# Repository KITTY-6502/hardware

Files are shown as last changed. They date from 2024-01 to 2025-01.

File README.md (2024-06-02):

# KITTY Computer

the KITTY is a 65c02 homebrew kit microcomputer designed around text mode graphics and cartridge media. It is fully open source, and uses exclusively in-production parts. 

Quick Specs:

* **Bus Speed:** 3Mhz
* **CPU:*** w65c02s @~2.2Mhz (average)
* **RAM:** 28Kb SRAM
* **Video:** Custom, 256x256pixels, a text mode display using a preset font, 32x32 8x8 pixel characters, 16 color palette
* **Sound:** Custom, 8x1 Wavetable Audio, 3 melodic + 1 percussive channels, all with 4bit+4bit stereo volume control.
* **Input:** 40-Key Mechanical Keyboard
* **Media/Expansion:** 2 Cartridge Slots, each with up to 128x32Kb banks.
* **Interrupts:** /IRQ triggered when the video circuit has drawn the last visible pixels on the frame.
* **Output:** RGB PAL (50hz), via a SCART connector.

**[Computer Manual](https://smaldragon.github.io/KITTY)**
**[Schematic](Docs/schematics/v2a.pdf)**

Picture of Prototype Board
Test Program

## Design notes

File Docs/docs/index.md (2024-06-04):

# What is a KITTY? (an introduction)

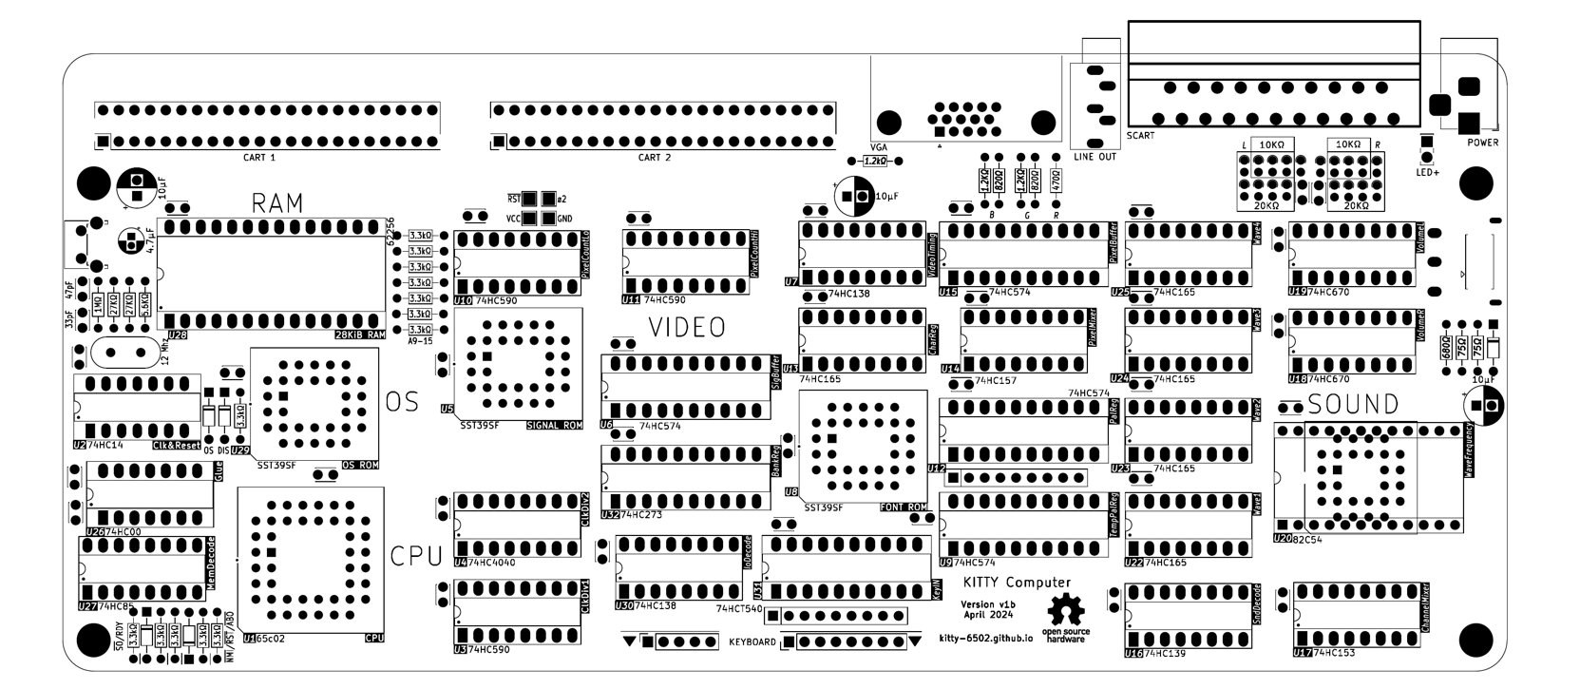
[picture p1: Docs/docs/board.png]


The **KITTY** (Kewl Interactive Text Terminal sYstem) is a new 8bit 65c02-based fantasy homebrew computer developed by smal (that's me!), it envisions a microcomputer which never existed, with colorful text based graphics, an unique sound system and, oddly, cartridges as its main form of media and expansion.

Looking at the back of the system, we see an austere sight: An audio/video SCART port and two cartridge ports, and not a single peripheral port in sight! In fact, the basic cartridge that came bundled with every sold system had to include audio jacks on the cart itself in order to allow one to save their programs. Rather than a failure, this was the driving design philosphy behind the cost-saving design of the KITTY, to allow programs to come bundled with any extra features they might need, while leaving the base design unburdened, after all, what use would an extra port or feature be without an accompaning program to use it?

Sadly we do not have access to this particular alternate reality (perhaps because it is imaginary), so we can not judge the success of this particular design approach. However, I have designed and built a version of this system here in our own world for anyone to play with, and this is what this manual is all about.

I wish you a fun and (hopefully) educational time exploring this little system



> The original v0a board prototype

## Details

The current iteration of the KITTY board (v1a) uses only in-production parts and is open hardware that anyone can tweak and build upon, on the v1a board custom features like video and audio are all implemented through the means of discrete 74-series logic. All ICs are in either Dual-In-Line packages or PLCC packages using through hole sockets, so that no surface mount soldering is required for assembly and all ICs can be easily placed or removed.

Finally, all components, their values, and their general function within the circuit are written on the silkscreen itself, as I wanted a board that was easy to assemble and understand.

## SPECS

* **CPU** 65c02 @ ~2.2mhz (3mhz bus)
* **RAM** 28Kb Static Ram
* **MEDIA** 2 cartridge slots for programs or expansion, each with up to 128 banks of 32kb for a theoretical max of 4Mb per cartridge
* **VIDEO** Custom, 8x8 pixel characters on a 32x32 grid, selectable background/foreground colors from a pallette of 16 
* **AUDIO** Custom, 4 channels of 8x1 wavetable audio (3 melodic, 1 percussive), with 4bit+4bit stereo volume control
* **INPUT** Custom 40-key mechanical keyboard 
* **OUTPUT** SCART, using RGB progressive PAL @50.1hz
* **POWER** 5v DC via a center positive barrel jack

```
    .--------------------.                          .----------------------.
    | 64KiB Memory Space |                          |          I/O         |
    |--------------------|                          |--------------+-------|
    |                    | $0000                    | KEY 1        | $7000 |
    |                    | $0800                    | KEY 2        | $7010 |
    |                    | $1000                    | KEY 3        | $7020 |
    |                    | $1800                    | KEY 4        | $7030 |
    |                    | $2000                    | KEY 5        | $7040 |
    |      WORK RAM      | $2800                    | BANK Register| $70D0 |
    |       28KiB        | $3000                    | CH Freq 1    | $70E0 |
    |                    | $3800                    | CH Freq 2    | $70E1 |
    |                    | $4000                    | CH Freq 3    | $70E2 |
    |                    | $4800                    | CH Control   | $70E3 |
    |                    | $5000                    | CH Volume 1  | $70F0 |
    |                    | $5800                    | CH Volume 2  | $70F1 |
    |                    | $6000                    | CH Volume 3  | $70F2 |
    |   (video memory)   | $6800                    | CH Volume 4  | $70F3 |
    |--------------------| $7000                    | CH Waveform 1| $70F4 |
    |        I/O         | $7800                    | CH Waveform 2| $70F5 |
    |--------------------| $8000                    | CH Waveform 3| $70F6 |
    |                    | $8800                    | CH Waveform 4| $70F7 |
    |                    | $9000                    +--------------+-------+
    |                    | $9800
    |                    | $A000
    |     CART SPACE     | $A800
    |       32KiB        | $B000
    |    (256 Banks)     | $B800
    |                    | $C000
    |                    | $C800
    |                    | $D000
    |                    | $D800
    |                    | $E000
    |                    | $E800
    |                    | $F000
    |                    | $F800
    +--------------------+

```

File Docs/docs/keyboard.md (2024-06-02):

# Keyboard

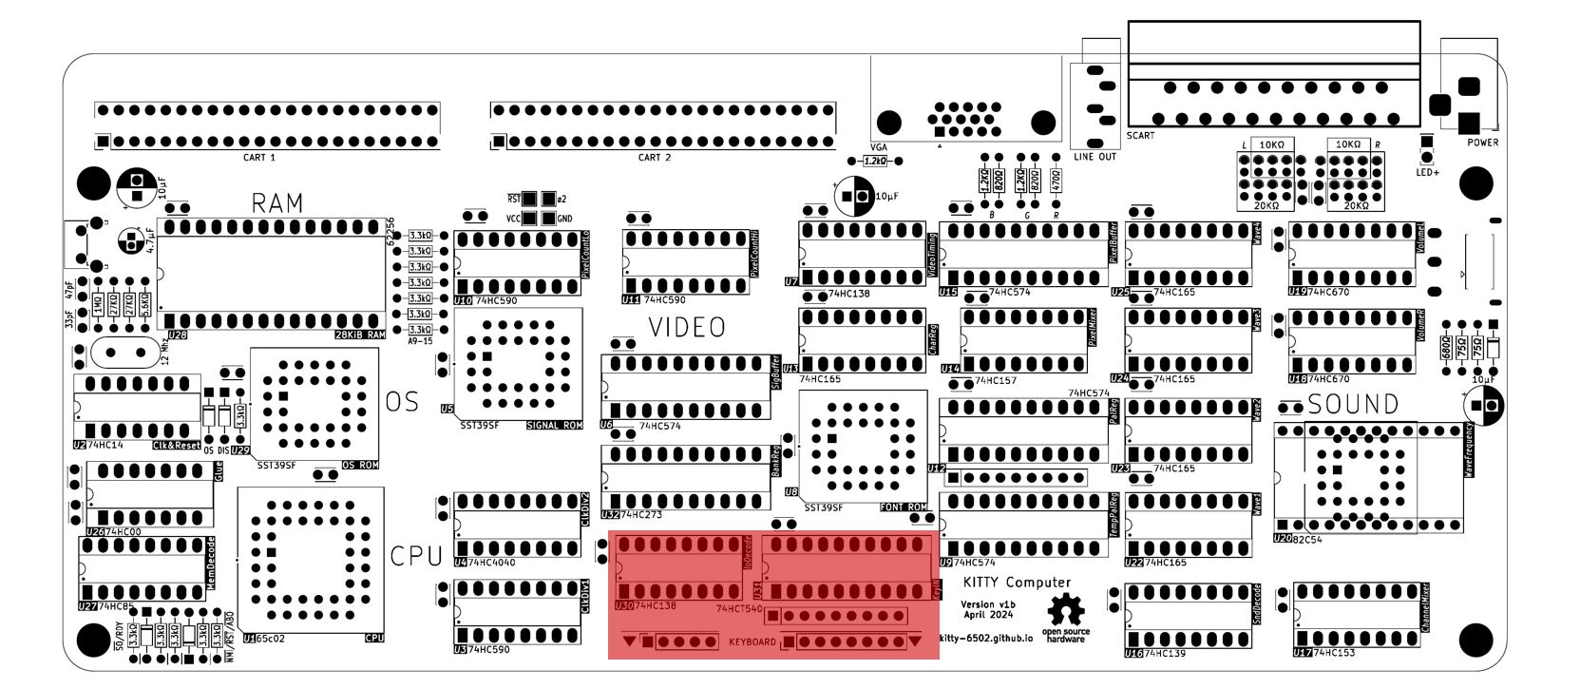
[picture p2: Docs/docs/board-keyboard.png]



The KITTY uses a custom 40-key mechanical keyboard for input, which is connected to the main board via two cables.

The keyboard can be read directly by the cpu through means of 5 Keyboard Row Registers, where each bit in the byte represents the current state of a particular key (**0**=unpressed **1**=pressed).

| Address | Mode |  Description | Format (bit 7-0)|
|---|---|---|---|
| `$7000` |  R | Keyboard Row 1 | `Ctrl` `X` `C` `Space` `↑` `←` `↓` `→` |
| `$7010` |  R | Keyboard Row 2 | `Menu` `Z` `F` `B` `N` `|` `.` `Enter` |
| `$7020` |  R | Keyboard Row 3 | `Shift` `A` `D` `V` `H` `M` `L` `Backspace`|
| `$7030` |  R | Keyboard Row 4 | `Alt` `Q` `S` `G` `Y` `J` `K` `P`|
| `$7040` |  R | Keyboard Row 5 | `Esc` `W` `E` `R` `T` `U` `I` `O`|

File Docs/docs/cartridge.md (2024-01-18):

# Cartridges and Memory

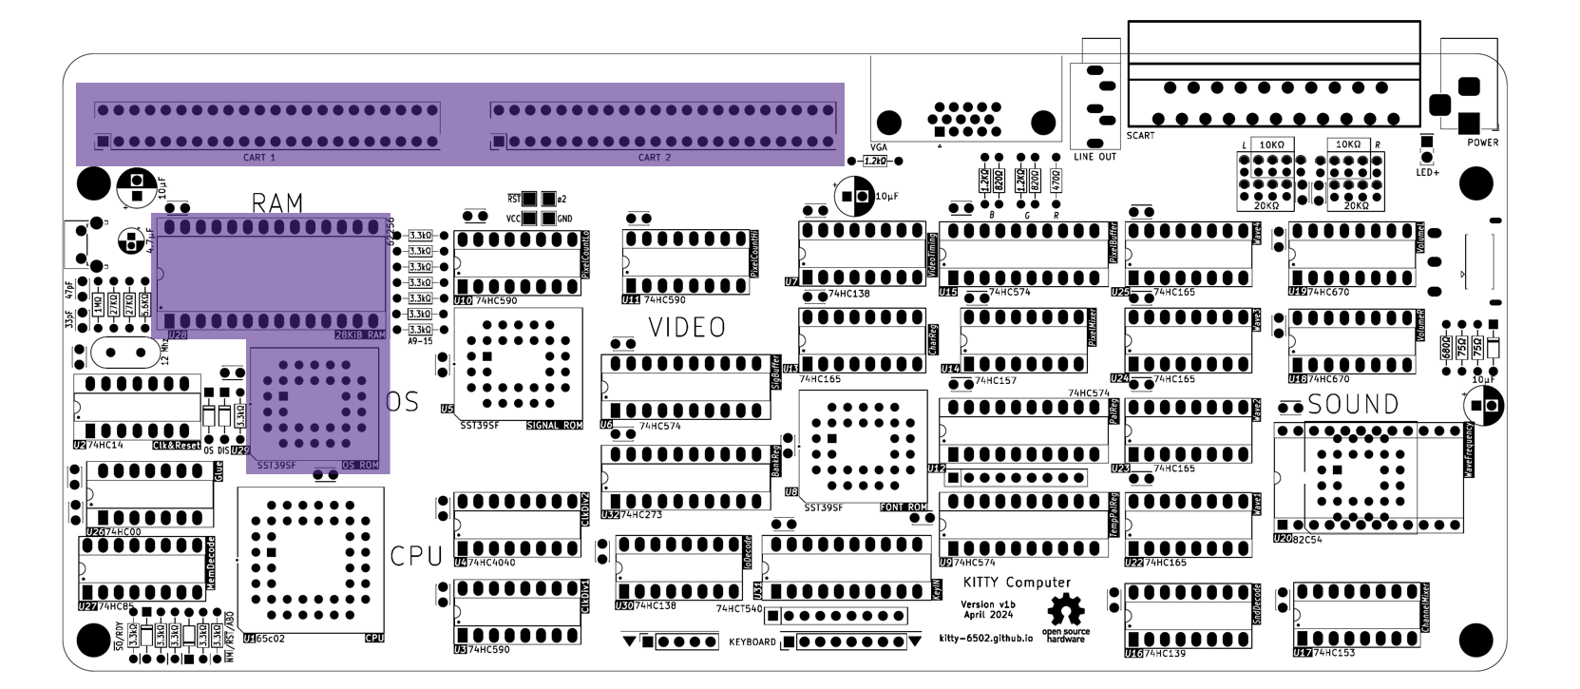
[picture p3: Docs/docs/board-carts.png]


| Address | Mode |  Description | Format |
|---|---|---|---|
| `$0000-$6FFF`| R/W | System Ram | 28Kb of static ram |
| `$70D0` |  W | BANK Register  | `%cccc_bbbb` **c**artridge `0-1` and **b**ank `0-127` |
| `$8000-$FFFF` | R/W | Cartridge Space | 32Kb banked window

Cartridges are the main form of media and expansion used by the KITTY, with the system being able to hold 2 cartridges at a time (dubbed Slot 1 and Slot 2), each of which have an individual 4Mb address space, that can be filled with programs, extra ram or peripheral devices.

They are accessed through the upper half of the KITTY memory map (`$8000-$FFFF`), which acts as 32Kb window into the contents of one of the 2 carts. This window can then be controlled by writing to the BANK register located at `$70D0`. The upper bit will determine the cartridge, while the 7 remaining bits will select one of up to 128 banks within it.

Finally, on hardware reset/power-on the BANK register will always be cleared to $00. As such, CPU will always begin code execution from the Bank 0 of Slot 1.

## OS ROM

The "OS ROM" or "TEST ROM" is a rom present on the main KITTY PCB, which is virtuaslly mapped to cartridge Slot 1. As of time of writing (2024-01-05), the contents of this chip have not been defined.

## Cartridge Pinout

The 2 cartridge slots use standard right-angle edge connectors, with 44-pins, and a spacing of 2.54mm (0.1"):



* `D0-D7`  - 8bit data bus
* `A0-A15` - 16bit address bus
* `B0-B7`  - 8bit BANK register
* `M3`     - 3Mhz Bus Clock
* `R/#W`   - Read/Write Signal, standard 65xx polarity
* `#R/W`   - Read/Write Signal, inverted polarity
* `#RESET` - System Reset
* `#NMI`   - Non-Maskable Interrupt
* `#CART`  - Cartridge Space Access `A15 NAND M3`
* `#SLOT ENABLE`- If the current slot is enabled (according to bit 7 of BANK)
* `ROM DISABLE` - Disable OS ROM (slot 1 only)
* `x` - Unconnected

`ROM DISABLE` is a signal that, when pulled high by a cartridge in Slot 1, disables the OS ROM. A cart can choose to leave this signal permanently high, to completely replace the OS ROM, or it can instead choose to implement more complex address decoding logic, allowing both to coexist within the same slot.

# Flash ROM Cart

The flash cart uses a standard re-writable 39sf flash NOR chip, which are avaliable in sizes of 128KiB, 256KiB and 512KiB.

# Serial Cart

The serial cart allows communication between the KITTY and a modern computer via serial over USB, the KITTY is connected to a `16c550` UART, while the desktop is connected to a `MCP2221A` UART. The cart shares slot 1 with the **OS ROM**, being active/replacing it when **BANK** is `$40` or higher (bit 6 high)

# RAM Cart

The RAM cart provides either 128KiB or 512KiB of SRAM memory.

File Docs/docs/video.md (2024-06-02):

# Video System

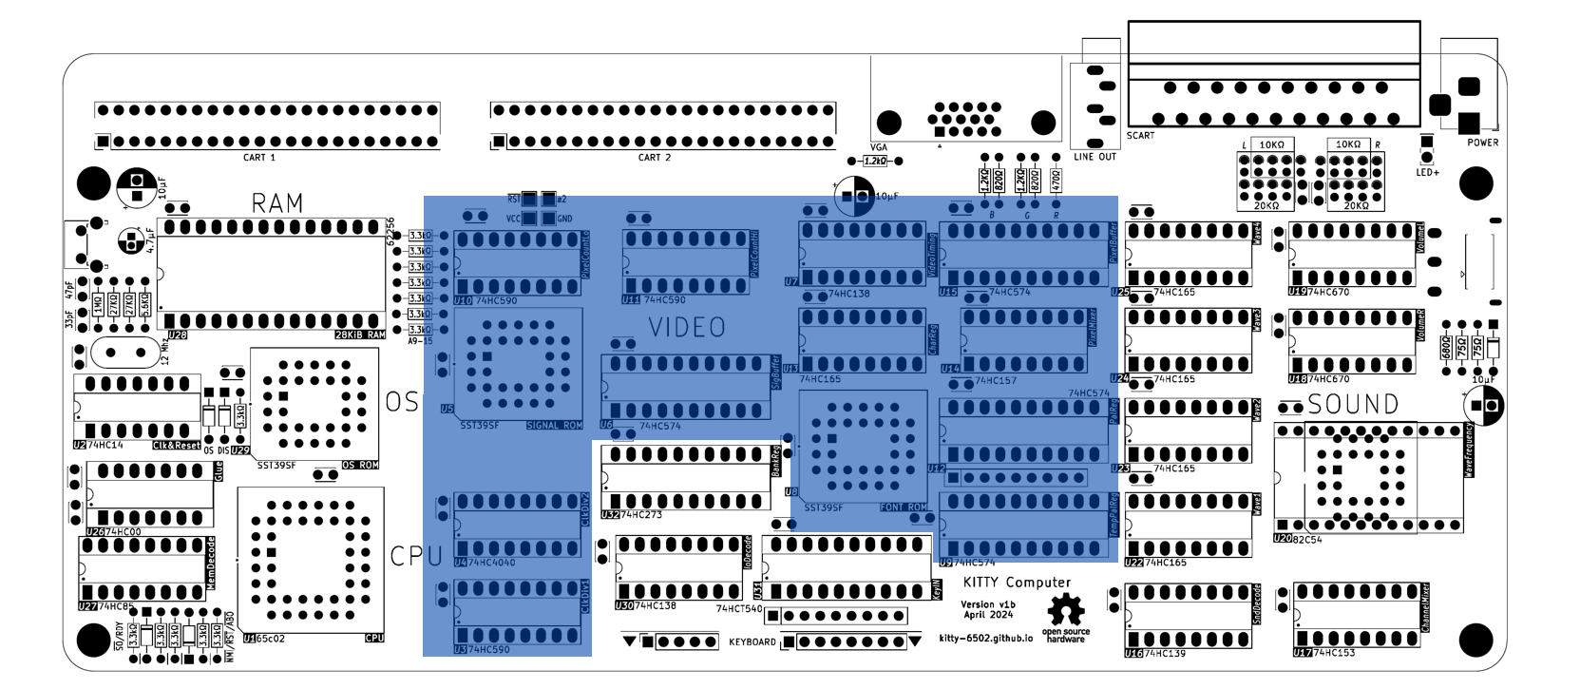
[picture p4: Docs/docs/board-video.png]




The KITTY's video output is a text based display containing 32 by 32 tiles of 8 by 8 pixels. Each tile can be set to one of 256 different characters from a fixed font, with foreground and background colors chosen from a palette of 16.

The data for the display is located directly in system ram:

| Address |  Description | Format |
|---|---|---|
| `$6800-$6BFF` | Display Characters | `0-255` extended ascii character |
| `$6C00-$6FFF` | Display Color | `%ffff_bbbb` **f**oreground and **b**ackground |

## Palette

An approximation of the KITTY's color palette:



## Font

The font is a variation of ascii:

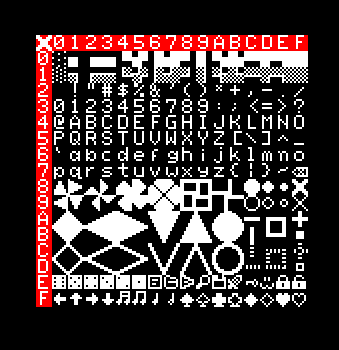
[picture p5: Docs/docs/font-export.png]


# Details

The color palette is generated from the following resistor DAC:



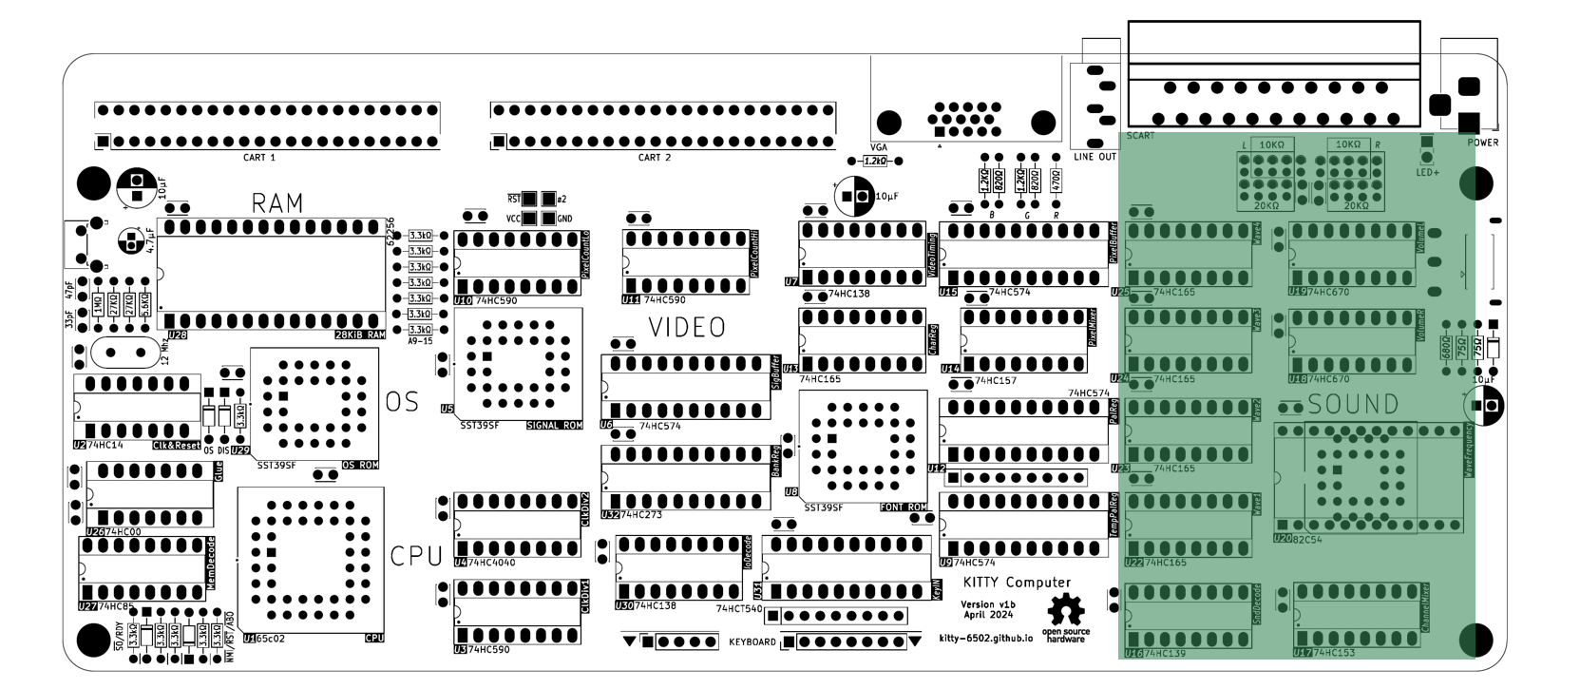
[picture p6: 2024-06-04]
Docs/docs/board-audio.png

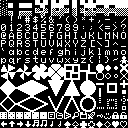
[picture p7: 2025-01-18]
Code/font.png

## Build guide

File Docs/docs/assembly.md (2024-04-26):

# System Assembling

## Bill of Materials

### Integrated Circuits

Name        | Qty | Package             | Description
------------|-----|---------------------|-------------
74HC00      |  1  | dip-14              | quad NAND
74HC14      |  1  | dip-14              | hex NOT (Schmitt-Trigger)
74HC85      |  1  | dip-16              | 4-bit Comparator
74HC138     |  2  | dip-16              | 3to8 Decoder
74HC139     |  1  | dip-16              | dual 2to4 Decoder
74HC153     |  1  | dip-16              | dual 4to1 Selector
74HC157     |  1  | dip-16              | quad 2to1 Selector
74HC165     |  5  | dip-16              | parallel-in Shift Register
74HC273     |  1  | dip-20              | 8-bit Register w/Reset
74HC574     |  4  | dip-20              | 8-bit Register w/3-State
74HC590     |  3  | dip-16              | 8-bit Sync Counter
74HC670     |  2  | dip-16              | 4x4-bit Register
74HC4040    |  1  | dip-16              | 12-bit Ripple Counter
74HCT540    |  1  | dip-20              | 8-bit Buffer (Inverting)
82c54       |  1  | dip-24-wide/plcc-28 | Tripple Timer
62256       |  1  | dip-28-wide         | 32KiB Sram
39SF040     |  3  | plcc-32             | 512KiB Nor Flash
65c02       |  1  | plcc-44             | 8-bit CPU

### Sockets

Name        | Qty |
------------|-----|
dip-14      |  2  |
dip-16      | 17  |
dip-20      |  6  |
dip-24-wide*|  1  |
dip-28-wide |  1  |
plcc-28*    |  1  |
plcc-32     |  3  |
plcc-44     |  1  |

> *1 Use either dip-24w or plcc depending on chosen 82c54 package

### Passives

Type              | Value               | Qty |
------------------|---------------------|-----|
12Mhz Quartz      | HC49                |  1  |
Diode             | 1n4148              |  5  |
Led               | Rectangular 2mmx5mm |  1  |
Led Holder        | 15mm Holder         |  1  |
Ceramic Capacitor | 33pF                |  1  |
Ceramic Capacitor | 47pF                |  1  |
Ceramic Capacitor | 100nF               | 34  |
Polar   Capacitor | 4.7µF               |  1  |
Polar   Capacitor | 10µF                |  3  |
Resistor          | 75Ω                 |  2  |
Resistor          | 470Ω                |  1  |
Resistor          | 680Ω                |  1  |
Resistor          | 820Ω                |  2  |
Resistor          | 1.2KΩ               |  2  |
Resistor          | 3.3KΩ               | 12  |
Resistor          | 5.6KΩ               |  1  |
Resistor          | 10KΩ                |  6  |
Resistor          | 20KΩ                | 10  |
Resistor          | 27KΩ                |  2  |
Resistor          | 1MΩ                 |  1  |

#### Keyboard

Type              | Value               | Qty |
------------------|---------------------|-----|
Diode             | 1n4148              | 45  |

### Switches and Connectors

Type                                        | Qty | Function
--------------------------------------------|-----|-----------
5x2.1 DC Power Jack                         |  1  | Power In
SCART Female (no ears)                      |  1  | Audio/Video Out
PJ-325                                      |  1  | Audio Out
VGA Female Connector                        |  1  | Video Out
Right Angle 2.54mm 44Pin Edge Connector     |  2  | Cartridge Slot
Right Angle Tactile Switch                  |  1  | Reset Button
SS-12D11-G5 Slide Switch                    |  1  | Power Switch
8-pin 2.54mm JST Vertical                   |  1  | Keyboard Connector
5-pin 2.54mm JST Vertical                   |  1  | Keyboard Connector

#### Keyboard
Type                                        | Qty | Function
--------------------------------------------|-----|-----------
8-pin 2.54mm JST Horizontal                 |  1  | Keyboard Connector
5-pin 2.54mm JST Horizontal                 |  1  | Keyboard Connector
2.00U Stabilizer                            |  1  | Return Stabalizer
6.25U Stabilizer                            |  1  | Spacebar Stabalizer
MX Switch/Kailh Low-Profile                 | 40  | Keyboard Switches
1U KeyCap                                   | 32  | Letters, Arrows, Escape
1.25U KeyCap                                |  3  | BackSpace, Alt, Ctrl
1.5U KeyCap                                 |  1  | BackSlash
1.75U KeyCap                                |  2  | Shift, Math
2U KeyCap                                   |  1  | Enter
6.25U KeyCap                                |  1  | SpaceBar

Due to the uncommon layout of the keyboard, it is preferable to pick a set of keycaps using a profile of uniform height, such as:

* DSA
* XDA
* G20
* MOA
* KAT

## Assembly

This guide approachs assembling the KITTY through a series of steps where one subsystem is built, tested and debugged, before moving on to the next step. Hoping this way to both avoid mistakes, and give you a better understanding of how the system works.

### Step 1 - Power Input

Install Power Jack, Power Switch, Big Decap, Power LED & its resistor.

### Step 2 - Clock and Reset

Install '14 and the passives for the clock and reset

Pierce Oscillator circuit 

### Step 3 - Clock Dividers

Install '590 and '4040

### Step 4 - First "Video" Output

Install Sig ROM, '574, SCART and VGA Ports, Mode and Sync components

The signal ROM is controlled by the clock dividers built in the previous step, and is in charge of:

* generating the video sync signals
* determining the visible portion of the screen
* generating a CPU interrupt request when the very last character on a frame is rendered
* resetting the clock counters at the end of the frame.

Finally a '574 latch is used to buffer the output of the Sig ROM before sending it to the rest of the system (to avoid signal transition glitches)

Connecting a video cable to an appropriate known-working display, there will be no image yet, but the signal should now be recognized by the display as Progressive PAL 50fps (what your display calls may vary). If the display shows a "no signal" message then most likely a mistake was made somewhere in this building step.

### Step 5 - Random Colors

Coordination '138, BOXY palette buffers, BOXY color mixer, BOXY out buffer, Color DAC

### Step 6 - RAM, memory mapping, and Stable Colors

SRAM, '85, '00, '590, '590

###Step 7 - Random Characters

'165, FONT ROM

### Step 8 - Installing the CPU

'w65c02

### Step 9 - Adding the test rom

ROM, '138, '273

### Step 10 - The Keyboard

'541 + keyboard + headers

### Step 11 - Sound System

82c54, '670, '670, '153, Sound DAC, Sound Filters

### Step 12 - The Case

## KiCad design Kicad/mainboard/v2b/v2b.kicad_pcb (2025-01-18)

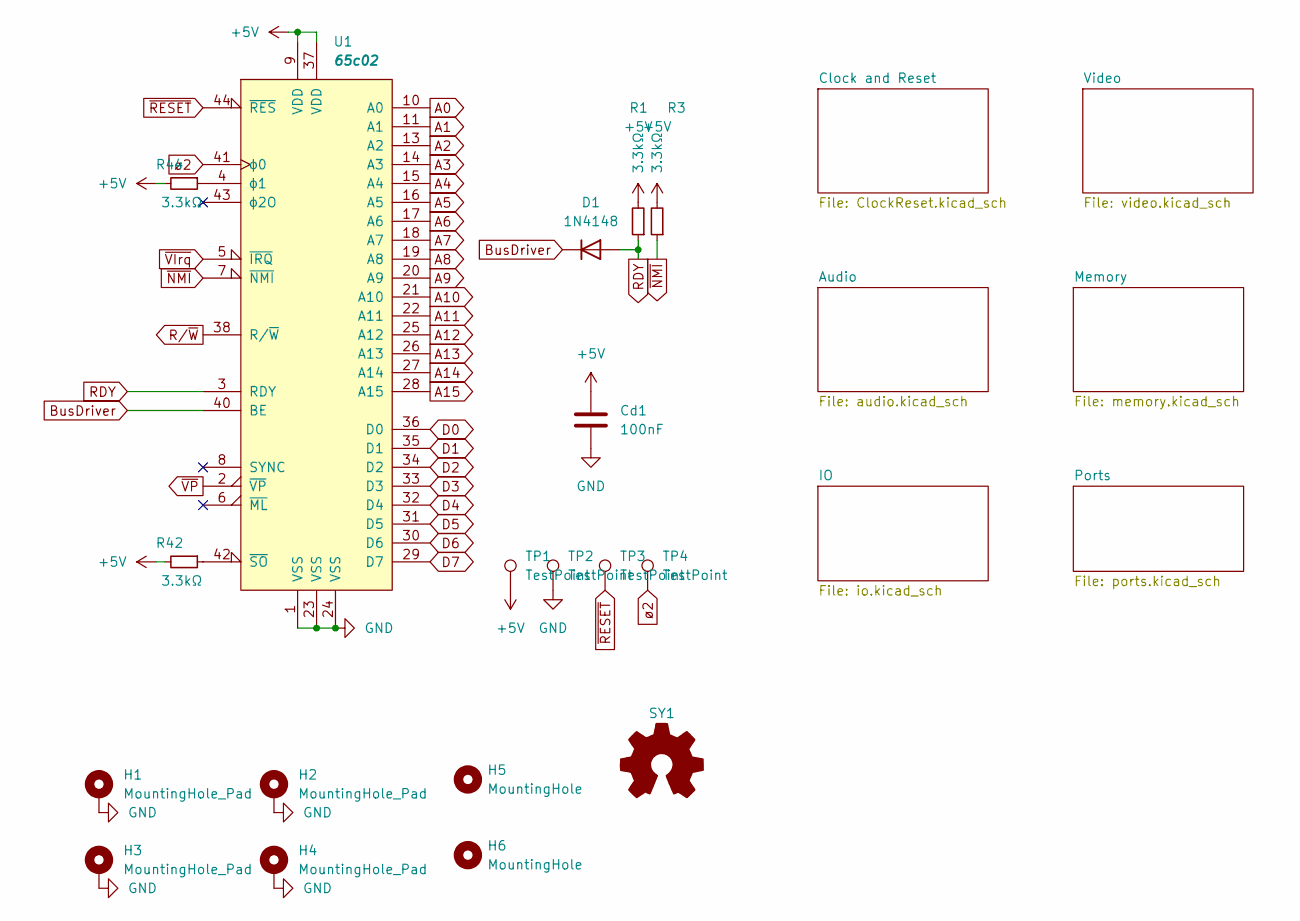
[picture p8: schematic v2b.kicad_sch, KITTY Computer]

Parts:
Cd1: 100nF; C_Disc_D3.0mm_W1.6mm_P2.50mm
D1: 1N4148; D_DO-34_SOD68_P7.62mm_Horizontal
H1, H2, H3, H4: MountingHole_Pad; MountingHole_3.2mm_M3_ISO14580_Pad
H5, H6: MountingHole; MountingHole_2.2mm_M2
R1, R3, R42, R44: 3.3kΩ; R_Horizontal
SY1: Logo_Open_Hardware_Small; OSHW-Logo_7.5x8mm_SilkScreen
TP1, TP2, TP3, TP4: TestPoint; TestPoint_Pad_2.0x2.0mm
U1: 65c02; PLCC-44_THT-Socket_TWEAK

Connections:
+5V: Cd1.1, R1.2, R3.2, R42.2, R44.2, TP1.1, U1.9 (VDD), U1.37 (VDD); also elsewhere on the board
A0: U1.10 (A0); also elsewhere on the board
A1: U1.11 (A1); also elsewhere on the board
A2: U1.13 (A2); also elsewhere on the board
A3: U1.14 (A3); also elsewhere on the board
A4: U1.15 (A4); also elsewhere on the board
A5: U1.16 (A5); also elsewhere on the board
A6: U1.17 (A6); also elsewhere on the board
A7: U1.18 (A7); also elsewhere on the board
A8: U1.19 (A8); also elsewhere on the board
A9: U1.20 (A9); also elsewhere on the board
A10: U1.21 (A10); also elsewhere on the board
A11: U1.22 (A11); also elsewhere on the board
A12: U1.25 (A12); also elsewhere on the board
A13: U1.26 (A13); also elsewhere on the board
A14: U1.27 (A14); also elsewhere on the board
A15: U1.28 (A15); also elsewhere on the board
BusDriver: D1.1 (K), U1.40 (BE); also elsewhere on the board
CLK2: TP4.1, U1.41 (ϕ0); also elsewhere on the board
D0: U1.36 (D0); also elsewhere on the board
D1: U1.35 (D1); also elsewhere on the board
D2: U1.34 (D2); also elsewhere on the board
D3: U1.33 (D3); also elsewhere on the board
D4: U1.32 (D4); also elsewhere on the board
D5: U1.31 (D5); also elsewhere on the board
D6: U1.30 (D6); also elsewhere on the board
D7: U1.29 (D7); also elsewhere on the board
GND: Cd1.2, H1.1, H2.1, H3.1, H4.1, TP2.1, U1.1 (VSS), U1.23 (VSS), U1.24 (VSS); also elsewhere on the board
unnamed: R42.1, U1.42 (~SO)
unnamed: R44.1, U1.4 (ϕ1)
RDY: D1.2 (A), R1.1, U1.3 (RDY)
R/~W: U1.38 (R/~W); also elsewhere on the board
~NMI: R3.1, U1.7 (~NMI); also elsewhere on the board
~RESET: TP3.1, U1.44 (~RES); also elsewhere on the board
~VIrq: U1.5 (~IRQ); also elsewhere on the board
~VP: U1.2 (~VP); also elsewhere on the board

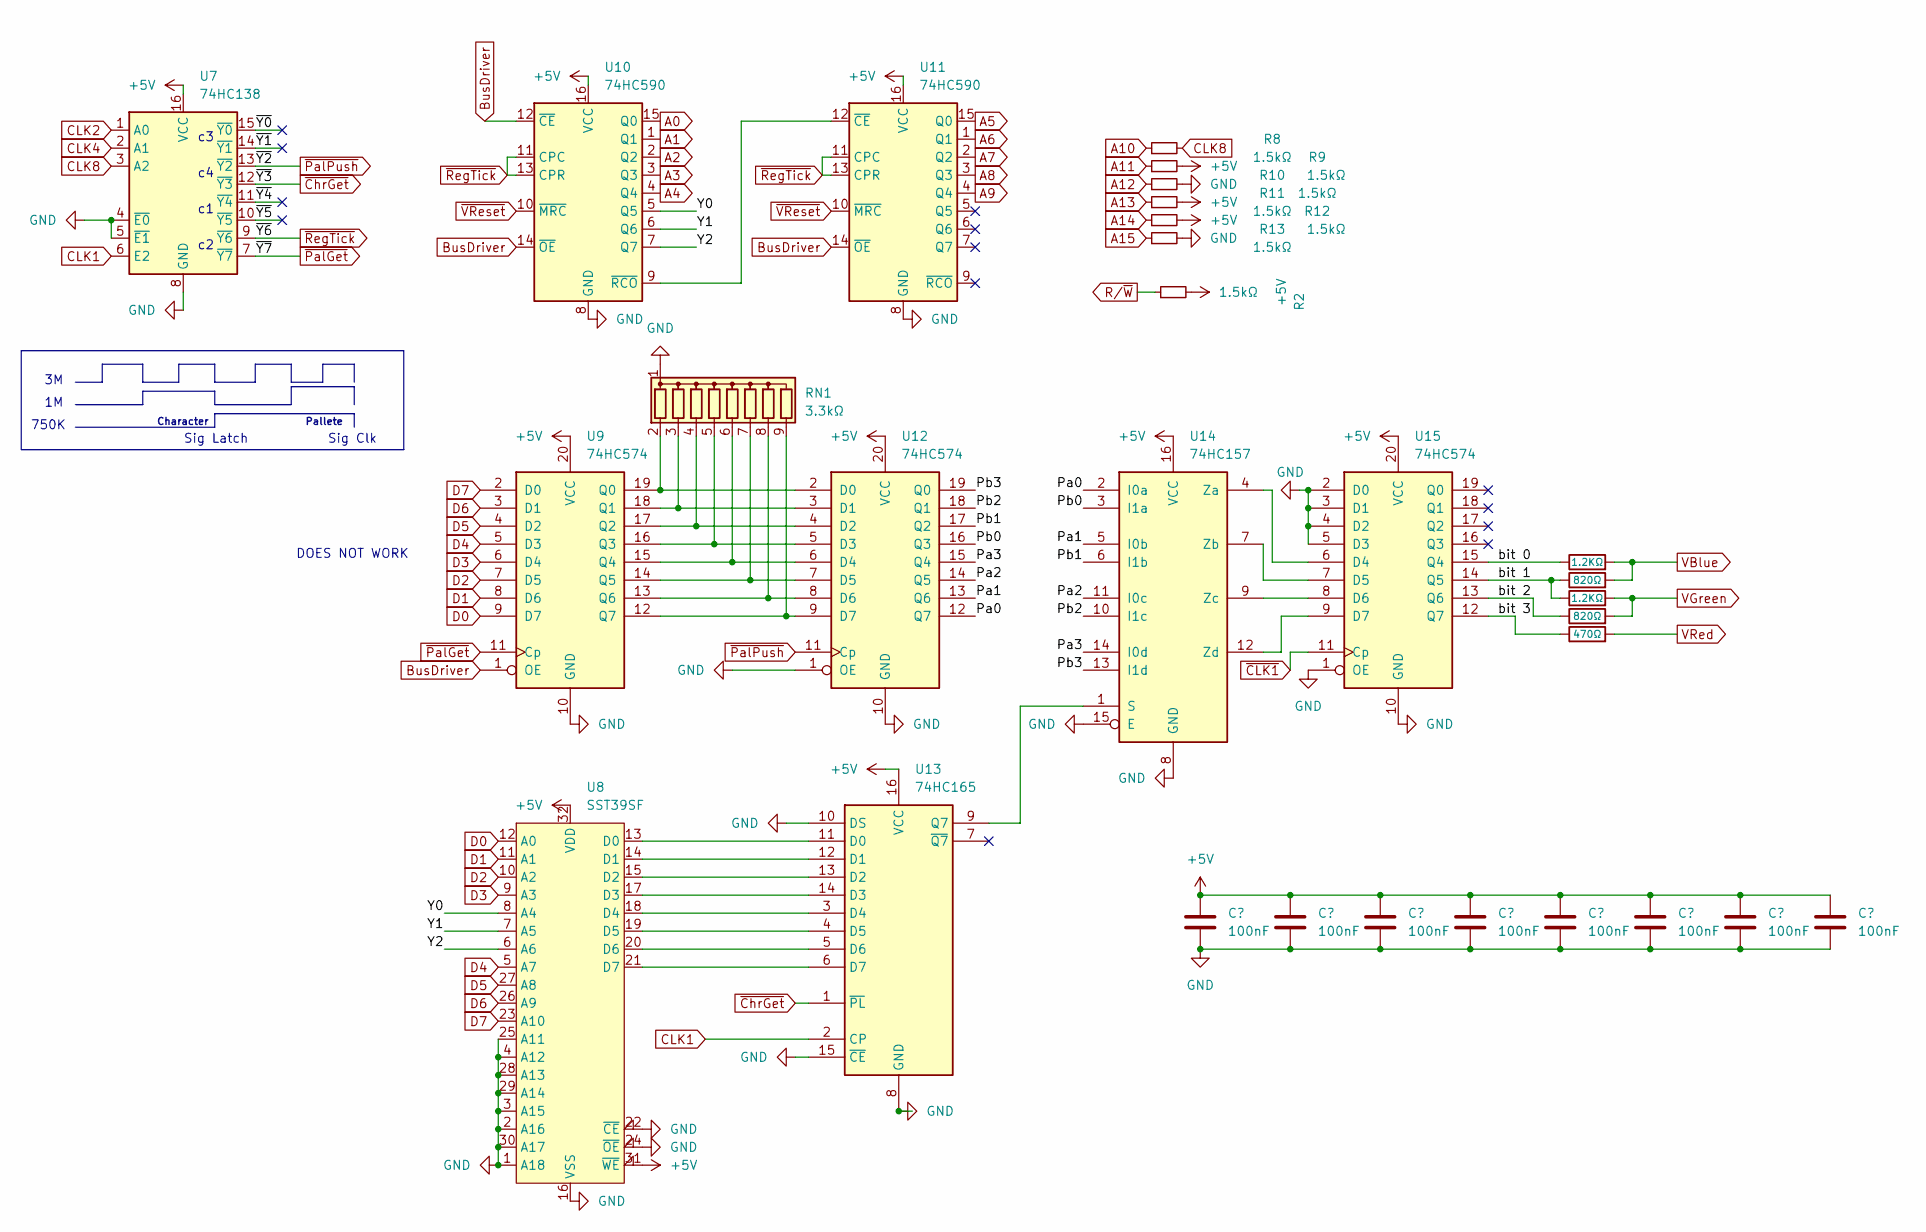
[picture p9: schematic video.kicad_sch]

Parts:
Cd8, Cd9, Cd10, Cd11, Cd12, Cd13, Cd14, Cd15: 100nF; C_Disc_D3.0mm_W1.6mm_P2.50mm
R2, R8, R9, R10, R11, R12, R13: 1.5kΩ; R_Horizontal
R14, R16: 1.2KΩ; R_Horizontal
R15, R17: 820Ω; R_Horizontal
R18: 470Ω; R_Horizontal
RN1: 3.3kΩ; R_Array_SIP9
U7: 74HC138; DIP-16_W7.62mm_Socket_LongPads_TWEAK
U8: SST39SF; PLCC-32_THT-Socket_TWEAK
U9, U12, U15: 74HC574; DIP-20_W7.62mm_Socket_LongPads_TWEAK
U10, U11: 74HC590; DIP-16_W7.62mm_Socket_LongPads_TWEAK
U13: 74HC165; DIP-16_W7.62mm_Socket_LongPads_TWEAK
U14: 74HC157; DIP-16_W7.62mm_Socket_LongPads_TWEAK

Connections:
+5V: Cd8.1, Cd9.1, Cd10.1, Cd11.1, Cd12.1, Cd13.1, Cd14.1, Cd15.1, R2.2, R9.2, R11.2, R12.2, U7.16 (VCC), U8.31 (~WE), U8.32 (VDD), U9.20 (VCC), U10.16 (VCC), U11.16 (VCC), U12.20 (VCC), U13.16 (VCC), U14.16 (VCC), U15.20 (VCC); also elsewhere on the board
/Video/Pa0: U12.12 (Q7), U14.2 (I0a)
/Video/Pa1: U12.13 (Q6), U14.5 (I0b)
/Video/Pa2: U12.14 (Q5), U14.11 (I0c)
/Video/Pa3: U12.15 (Q4), U14.14 (I0d)
/Video/Pb0: U12.16 (Q3), U14.3 (I1a)
/Video/Pb1: U12.17 (Q2), U14.6 (I1b)
/Video/Pb2: U12.18 (Q1), U14.10 (I1c)
/Video/Pb3: U12.19 (Q0), U14.13 (I1d)
/Video/Y0: U8.8 (A4), U10.5 (Q5)
/Video/Y1: U8.7 (A5), U10.6 (Q6)
/Video/Y2: U8.6 (A6), U10.7 (Q7)
/Video/bit 0: R14.1, U15.15 (Q4)
/Video/bit 1: R15.1, R16.1, U15.14 (Q5)
/Video/bit 2: R17.1, U15.13 (Q6)
/Video/bit 3: R18.1, U15.12 (Q7)
/Video/~Y0: U7.15 (~Y0)
/Video/~Y1: U7.14 (~Y1)
/Video/~Y4: U7.11 (~Y4)
/Video/~Y5: U7.10 (~Y5)
A0: U10.15 (Q0); also elsewhere on the board
A1: U10.1 (Q1); also elsewhere on the board
A2: U10.2 (Q2); also elsewhere on the board
A3: U10.3 (Q3); also elsewhere on the board
A4: U10.4 (Q4); also elsewhere on the board
A5: U11.15 (Q0); also elsewhere on the board
A6: U11.1 (Q1); also elsewhere on the board
A7: U11.2 (Q2); also elsewhere on the board
A8: U11.3 (Q3); also elsewhere on the board
A9: U11.4 (Q4); also elsewhere on the board
A10: R8.1; also elsewhere on the board
A11: R9.1; also elsewhere on the board
A12: R10.1; also elsewhere on the board
A13: R11.1; also elsewhere on the board
A14: R12.1; also elsewhere on the board
A15: R13.1; also elsewhere on the board
BusDriver: U9.1 (OE), U10.12 (~CE), U10.14 (~OE), U11.14 (~OE); also elsewhere on the board
CLK1: U7.6 (E2), U13.2 (CP); also elsewhere on the board
CLK2: U7.1 (A0); also elsewhere on the board
CLK4: U7.2 (A1); also elsewhere on the board
CLK8: R8.2, U7.3 (A2); also elsewhere on the board
D0: U8.12 (A0), U9.9 (D7); also elsewhere on the board
D1: U8.11 (A1), U9.8 (D6); also elsewhere on the board
D2: U8.10 (A2), U9.7 (D5); also elsewhere on the board
D3: U8.9 (A3), U9.6 (D4); also elsewhere on the board
D4: U8.5 (A7), U9.5 (D3); also elsewhere on the board
D5: U8.27 (A8), U9.4 (D2); also elsewhere on the board
D6: U8.26 (A9), U9.3 (D1); also elsewhere on the board
D7: U8.23 (A10), U9.2 (D0); also elsewhere on the board
GND: Cd8.2, Cd9.2, Cd10.2, Cd11.2, Cd12.2, Cd13.2, Cd14.2, Cd15.2, R10.2, R13.2, RN1.1 (common), U7.4 (~E0), U7.5 (~E1), U7.8 (GND), U8.1 (A18), U8.2 (A16), U8.3 (A15), U8.4 (A12), U8.16 (VSS), U8.22 (~CE), U8.24 (~OE), U8.25 (A11), U8.28 (A13), U8.29 (A14), U8.30 (A17), U9.10 (GND), U10.8 (GND), U11.8 (GND), U12.1 (OE), U12.10 (GND), U13.8 (GND), U13.10 (DS), U13.15 (~CE), U14.8 (GND), U14.15 (E), U15.1 (OE), U15.2 (D0), U15.3 (D1), U15.4 (D2), U15.5 (D3), U15.10 (GND); also elsewhere on the board
unnamed: RN1.2 (R1), U9.19 (Q0), U12.2 (D0)
unnamed: RN1.3 (R2), U9.18 (Q1), U12.3 (D1)
unnamed: RN1.4 (R3), U9.17 (Q2), U12.4 (D2)
unnamed: RN1.5 (R4), U9.16 (Q3), U12.5 (D3)
unnamed: RN1.6 (R5), U9.15 (Q4), U12.6 (D4)
unnamed: RN1.7 (R6), U9.14 (Q5), U12.7 (D5)
unnamed: RN1.8 (R7), U9.13 (Q6), U12.8 (D6)
unnamed: RN1.9 (R8), U9.12 (Q7), U12.9 (D7)
unnamed: U10.9 (~RCO), U11.12 (~CE)
unnamed: U8.13 (D0), U13.11 (D0)
unnamed: U8.14 (D1), U13.12 (D1)
unnamed: U8.15 (D2), U13.13 (D2)
unnamed: U8.17 (D3), U13.14 (D3)
unnamed: U8.18 (D4), U13.3 (D4)
unnamed: U8.19 (D5), U13.4 (D5)
unnamed: U8.20 (D6), U13.5 (D6)
unnamed: U8.21 (D7), U13.6 (D7)
unnamed: U13.9 (Q7), U14.1 (S)
unnamed: U14.4 (Za), U15.6 (D4)
unnamed: U14.7 (Zb), U15.7 (D5)
unnamed: U14.9 (Zc), U15.8 (D6)
unnamed: U14.12 (Zd), U15.9 (D7)
R/~W: R2.1; also elsewhere on the board
VBlue: R14.2, R15.2; also elsewhere on the board
VGreen: R16.2, R17.2; also elsewhere on the board
VRed: R18.2; also elsewhere on the board
~CLK1: U15.11 (Cp); also elsewhere on the board
~ChrGet: U7.12 (~Y3), U13.1 (~PL)
~PalGet: U7.7 (~Y7), U9.11 (Cp)
~PalPush: U7.13 (~Y2), U12.11 (Cp)
~RegTick: U7.9 (~Y6), U10.11 (CPC), U10.13 (CPR), U11.11 (CPC), U11.13 (CPR)
~VReset: U10.10 (~MRC), U11.10 (~MRC); also elsewhere on the board

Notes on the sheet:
Pallete
750K
Sig Clk
Character
DOES NOT WORK
Sig Latch

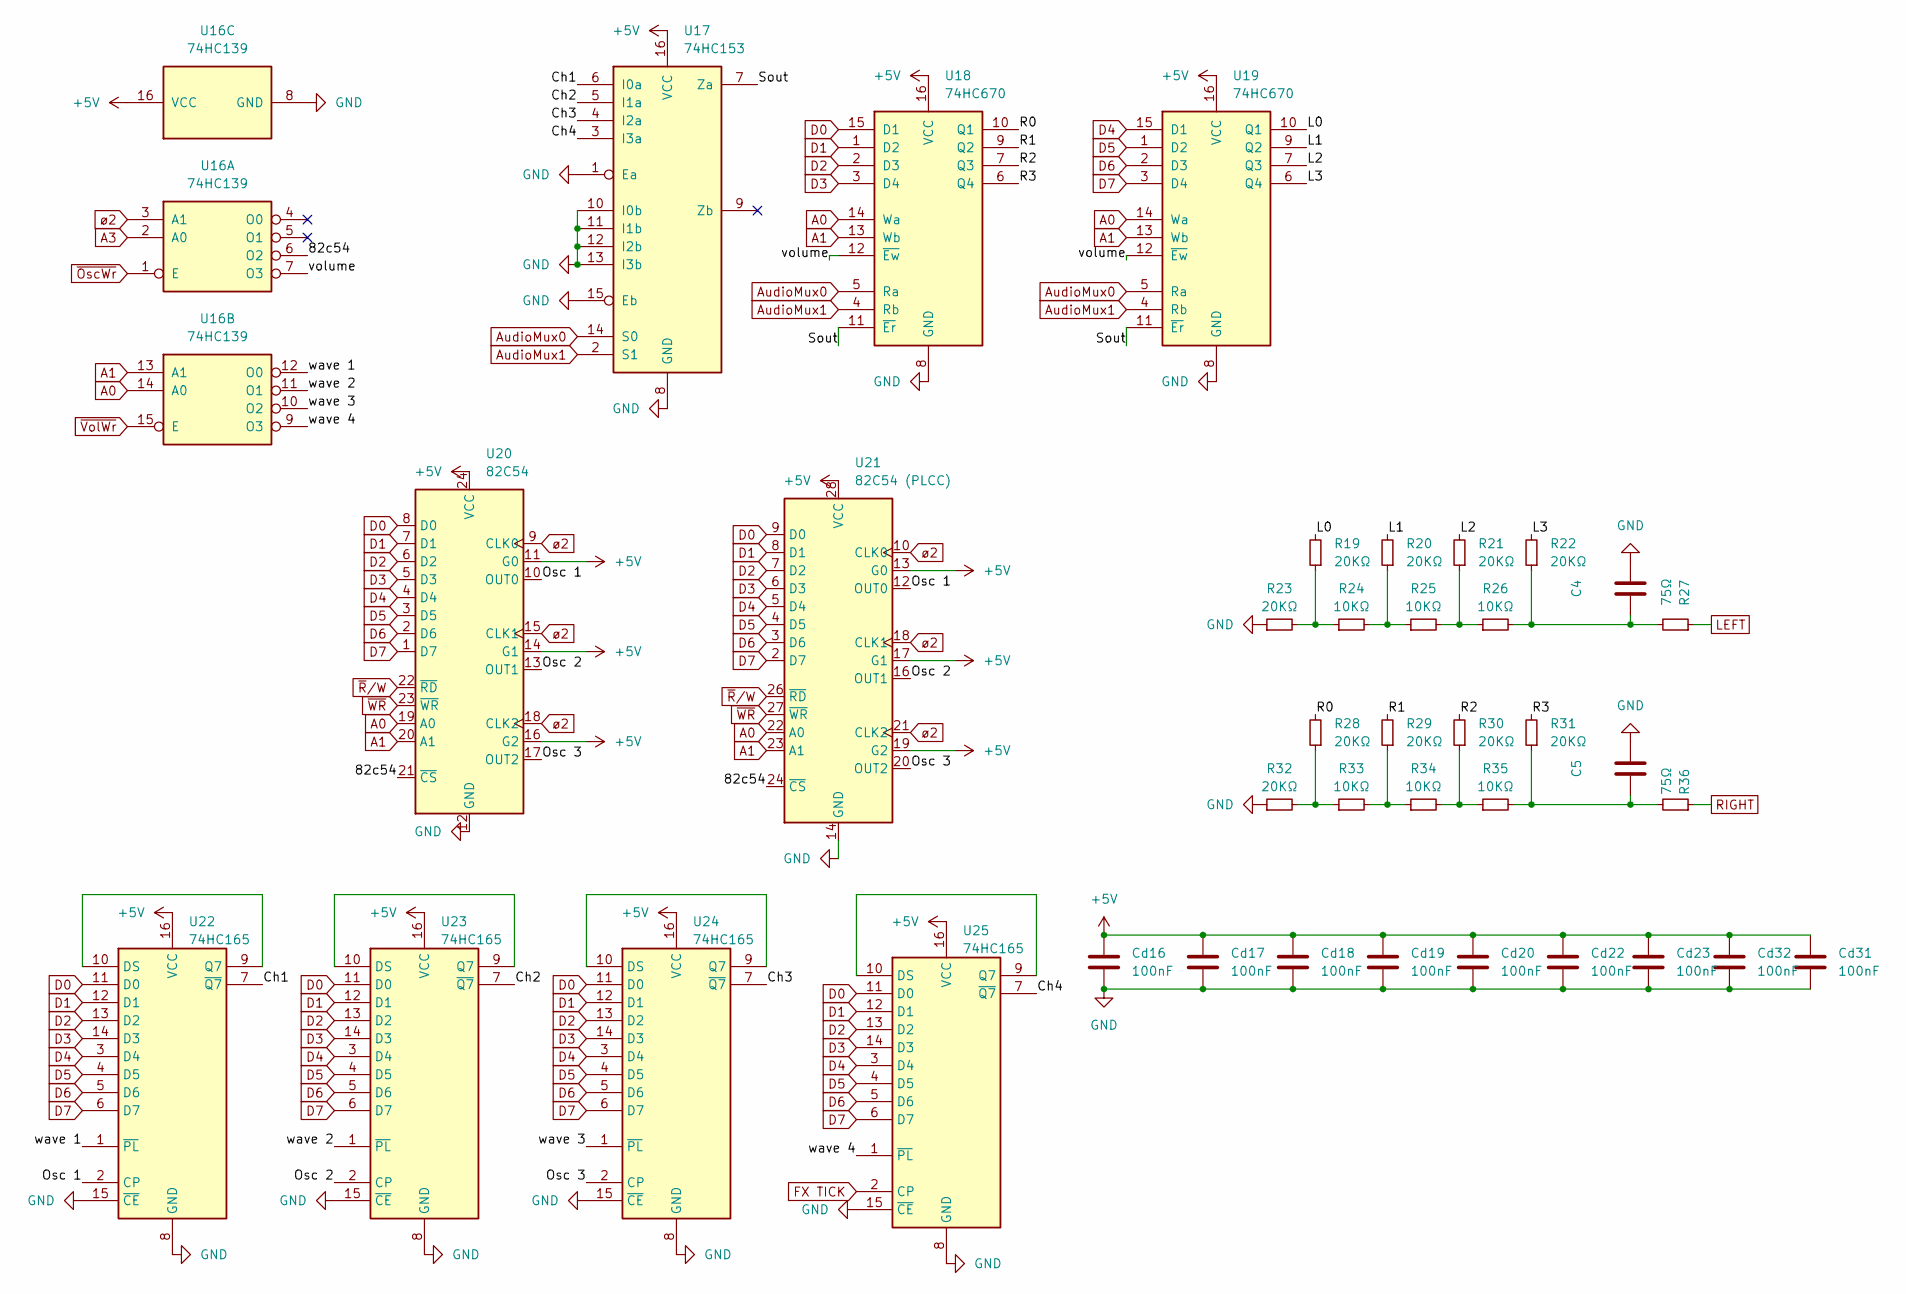
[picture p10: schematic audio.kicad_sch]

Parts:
C4, C5: 100nF; C_Disc_D3.0mm_W1.6mm_P2.50mm
Cd16, Cd17, Cd18, Cd19, Cd20, Cd22, Cd23, Cd31, Cd32: 100nF; C_Disc_D3.0mm_W1.6mm_P2.50mm
R19, R20, R21, R22, R23, R28, R29, R30, R31, R32: 20KΩ; RESISTOR VERT_WIDE
R24, R25, R26, R33, R34, R35: 10KΩ; RESISTOR VERT_WIDE
R27, R36: 75Ω; RESISTOR VERT_WIDE
U16: 74HC139; DIP-16_W7.62mm_Socket_LongPads_TWEAK
U17: 74HC153; DIP-16_W7.62mm_Socket_LongPads_TWEAK
U18, U19: 74HC670; DIP-16_W7.62mm_Socket_LongPads_TWEAK
U20: 82C54; DIP-24_W15.24mm_Socket_TWEAK
U21: 82C54 (PLCC); PLCC-28_THT-Socket_TWEAK
U22, U23, U24, U25: 74HC165; DIP-16_W7.62mm_Socket_LongPads_TWEAK

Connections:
+5V: Cd16.1, Cd17.1, Cd18.1, Cd19.1, Cd20.1, Cd22.1, Cd23.1, Cd31.1, Cd32.1, U16.16 (VCC), U17.16 (VCC), U18.16 (VCC), U19.16 (VCC), U20.11 (G0), U20.14 (G1), U20.16 (G2), U20.24 (VCC), U21.13 (G0), U21.17 (G1), U21.19 (G2), U21.28 (VCC), U22.16 (VCC), U23.16 (VCC), U24.16 (VCC), U25.16 (VCC); also elsewhere on the board
/Audio/82c54: U16.6 (O2), U20.21 (~CS), U21.24 (~CS)
/Audio/Ch1: U17.6 (I0a), U22.7 (~Q7)
/Audio/Ch2: U17.5 (I1a), U23.7 (~Q7)
/Audio/Ch3: U17.4 (I2a), U24.7 (~Q7)
/Audio/Ch4: U17.3 (I3a), U25.7 (~Q7)
/Audio/L0: R19.2, U19.10 (Q1)
/Audio/L1: R20.2, U19.9 (Q2)
/Audio/L2: R21.2, U19.7 (Q3)
/Audio/L3: R22.2, U19.6 (Q4)
/Audio/Osc 1: U20.10 (OUT0), U21.12 (OUT0), U22.2 (CP)
/Audio/Osc 2: U20.13 (OUT1), U21.16 (OUT1), U23.2 (CP)
/Audio/Osc 3: U20.17 (OUT2), U21.20 (OUT2), U24.2 (CP)
/Audio/R0: R28.2, U18.10 (Q1)
/Audio/R1: R29.2, U18.9 (Q2)
/Audio/R2: R30.2, U18.7 (Q3)
/Audio/R3: R31.2, U18.6 (Q4)
/Audio/Sout: U17.7 (Za), U18.11 (~Er), U19.11 (~Er)
/Audio/volume: U16.7 (O3), U18.12 (~Ew), U19.12 (~Ew)
/Audio/wave 1: U16.12 (O0), U22.1 (~PL)
/Audio/wave 2: U16.11 (O1), U23.1 (~PL)
/Audio/wave 3: U16.10 (O2), U24.1 (~PL)
/Audio/wave 4: U16.9 (O3), U25.1 (~PL)
A0: U16.14 (A0), U18.14 (Wa), U19.14 (Wa), U20.19 (A0), U21.22 (A0); also elsewhere on the board
A1: U16.13 (A1), U18.13 (Wb), U19.13 (Wb), U20.20 (A1), U21.23 (A1); also elsewhere on the board
A3: U16.2 (A0); also elsewhere on the board
AudioMux0: U17.14 (S0), U18.5 (Ra), U19.5 (Ra); also elsewhere on the board
AudioMux1: U17.2 (S1), U18.4 (Rb), U19.4 (Rb); also elsewhere on the board
CLK2: U16.3 (A1), U20.9 (CLK0), U20.15 (CLK1), U20.18 (CLK2), U21.10 (CLK0), U21.18 (CLK1), U21.21 (CLK2); also elsewhere on the board
D0: U18.15 (D1), U20.8 (D0), U21.9 (D0), U22.11 (D0), U23.11 (D0), U24.11 (D0), U25.11 (D0); also elsewhere on the board
D1: U18.1 (D2), U20.7 (D1), U21.8 (D1), U22.12 (D1), U23.12 (D1), U24.12 (D1), U25.12 (D1); also elsewhere on the board
D2: U18.2 (D3), U20.6 (D2), U21.7 (D2), U22.13 (D2), U23.13 (D2), U24.13 (D2), U25.13 (D2); also elsewhere on the board
D3: U18.3 (D4), U20.5 (D3), U21.6 (D3), U22.14 (D3), U23.14 (D3), U24.14 (D3), U25.14 (D3); also elsewhere on the board
D4: U19.15 (D1), U20.4 (D4), U21.5 (D4), U22.3 (D4), U23.3 (D4), U24.3 (D4), U25.3 (D4); also elsewhere on the board
D5: U19.1 (D2), U20.3 (D5), U21.4 (D5), U22.4 (D5), U23.4 (D5), U24.4 (D5), U25.4 (D5); also elsewhere on the board
D6: U19.2 (D3), U20.2 (D6), U21.3 (D6), U22.5 (D6), U23.5 (D6), U24.5 (D6), U25.5 (D6); also elsewhere on the board
D7: U19.3 (D4), U20.1 (D7), U21.2 (D7), U22.6 (D7), U23.6 (D7), U24.6 (D7), U25.6 (D7); also elsewhere on the board
FX TICK: U25.2 (CP); also elsewhere on the board
GND: C4.1, C5.1, Cd16.2, Cd17.2, Cd18.2, Cd19.2, Cd20.2, Cd22.2, Cd23.2, Cd31.2, Cd32.2, R23.1, R32.1, U16.8 (GND), U17.1 (Ea), U17.8 (GND), U17.10 (I0b), U17.11 (I1b), U17.12 (I2b), U17.13 (I3b), U17.15 (Eb), U18.8 (GND), U19.8 (GND), U20.12 (GND), U21.14 (GND), U22.8 (GND), U22.15 (~CE), U23.8 (GND), U23.15 (~CE), U24.8 (GND), U24.15 (~CE), U25.8 (GND), U25.15 (~CE); also elsewhere on the board
LEFT: R27.1; also elsewhere on the board
unnamed: C4.2, R22.1, R26.2, R27.2
unnamed: C5.2, R31.1, R35.2, R36.2
unnamed: R19.1, R23.2, R24.1
unnamed: R20.1, R24.2, R25.1
unnamed: R21.1, R25.2, R26.1
unnamed: R28.1, R32.2, R33.1
unnamed: R29.1, R33.2, R34.1
unnamed: R30.1, R34.2, R35.1
unnamed: U22.9 (Q7), U22.10 (DS)
unnamed: U23.9 (Q7), U23.10 (DS)
unnamed: U24.9 (Q7), U24.10 (DS)
unnamed: U25.9 (Q7), U25.10 (DS)
RIGHT: R36.1; also elsewhere on the board
~OscWr: U16.1 (E); also elsewhere on the board
~R/W: U20.22 (~RD), U21.26 (~RD); also elsewhere on the board
~VolWr: U16.15 (E); also elsewhere on the board
~WR: U20.23 (~WR), U21.27 (~WR); also elsewhere on the board

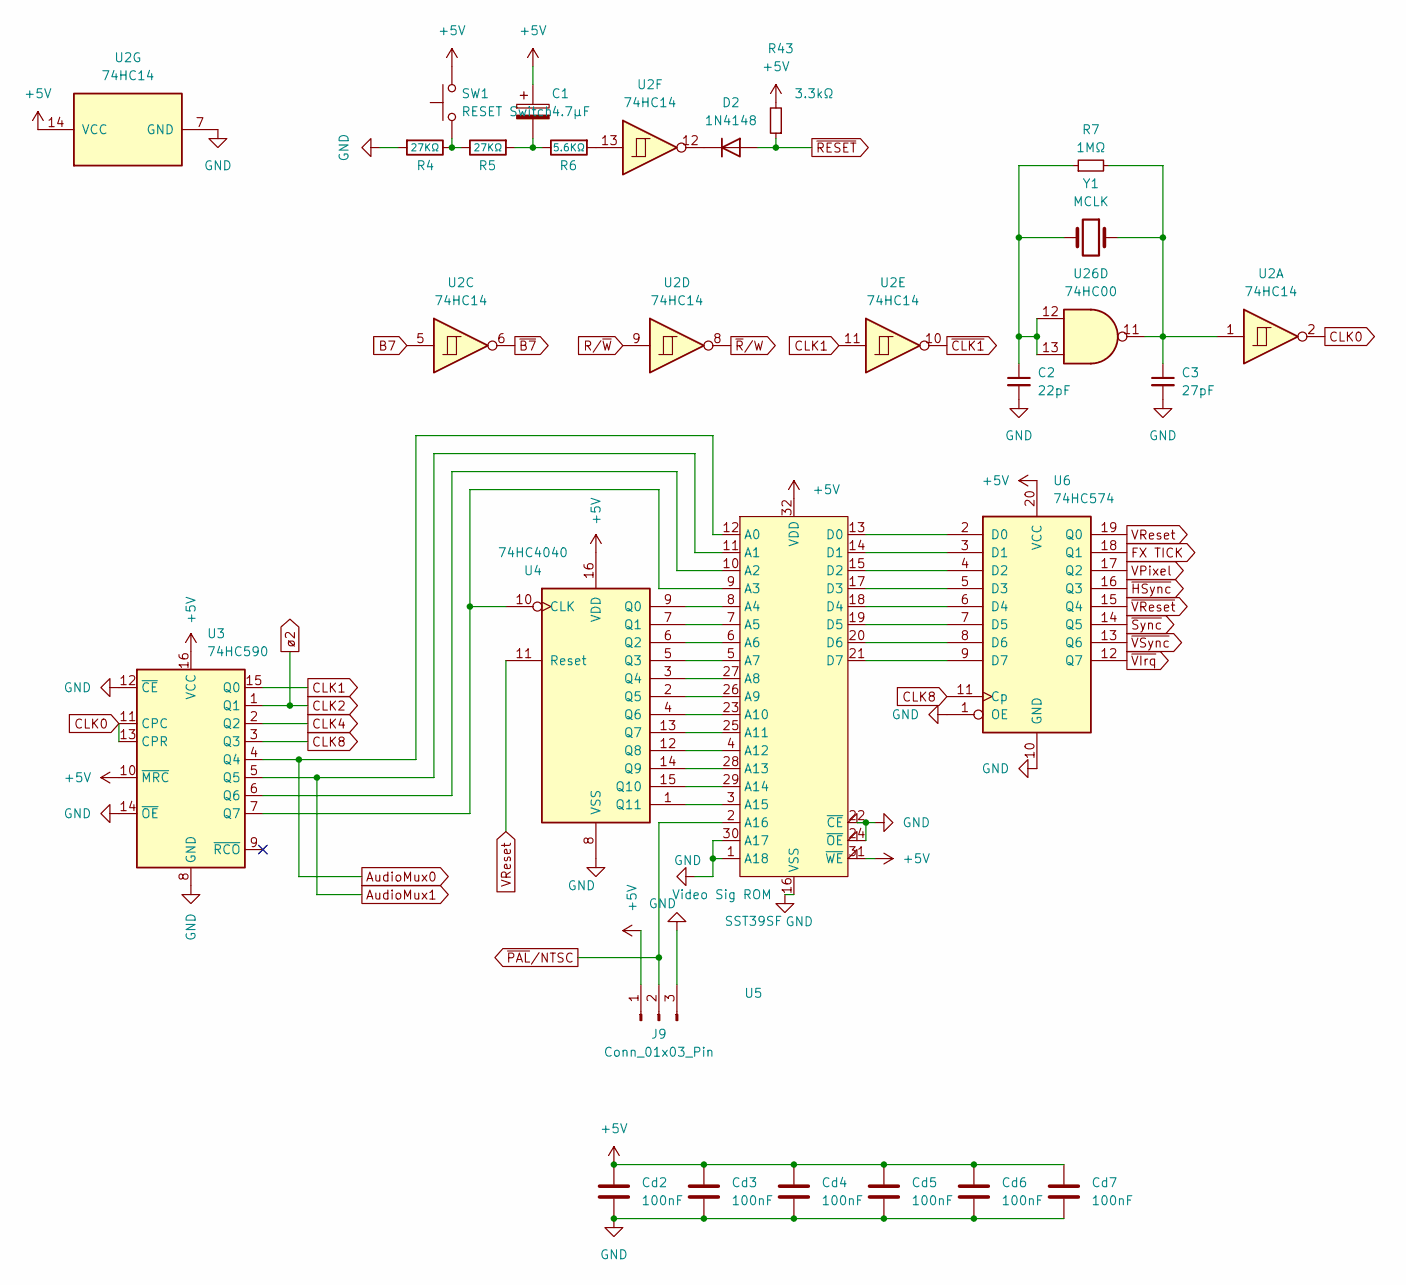
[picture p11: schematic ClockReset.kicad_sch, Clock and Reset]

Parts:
C1: 4.7µF; CP_Radial_D4.0mm_P1.50mm
C2: 22pF; C_Disc_D3.0mm_W1.6mm_P2.50mm
C3: 27pF; C_Disc_D3.0mm_W1.6mm_P2.50mm
Cd2, Cd3, Cd4, Cd5, Cd6, Cd7: 100nF; C_Disc_D3.0mm_W1.6mm_P2.50mm
D2: 1N4148; D_DO-34_SOD68_P7.62mm_Horizontal
J9: Conn_01x03_Pin; PinHeader_1x03_P2.54mm_Vertical
R4, R5: 27KΩ; R_Horizontal
R6: 5.6KΩ; R_Horizontal
R7: 1MΩ; R_Horizontal
R43: 3.3kΩ; R_Horizontal
SW1: RESET Switch; SW_Tactile_SPST_Angled_PTS645Vx83-2LFS
U2: 74HC14; DIP-14_W7.62mm_Socket_LongPads_TWEAK
U3: 74HC590; DIP-16_W7.62mm_Socket_LongPads_TWEAK
U4: 74HC4040; DIP-16_W7.62mm_Socket_LongPads_TWEAK
U5: SST39SF; PLCC-32_THT-Socket_TWEAK
U6: 74HC574; DIP-20_W7.62mm_Socket_LongPads_TWEAK
U26: 74HC00; DIP-14_W7.62mm_Socket_LongPads_TWEAK
Y1: MCLK; Crystal_HC49-U_Vertical

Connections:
+5V: C1.1, Cd2.1, Cd3.1, Cd4.1, Cd5.1, Cd6.1, Cd7.1, J9.1, R43.2, SW1.2, U2.14 (VCC), U3.10 (~MRC), U3.16 (VCC), U4.16 (VDD), U5.31 (~WE), U5.32 (VDD), U6.20 (VCC); also elsewhere on the board
AudioMux0: U3.4 (Q4), U5.12 (A0); also elsewhere on the board
AudioMux1: U3.5 (Q5), U5.11 (A1); also elsewhere on the board
B7: U2.5; also elsewhere on the board
CLK0: U2.2, U3.11 (CPC), U3.13 (CPR)
CLK1: U2.11, U3.15 (Q0); also elsewhere on the board
CLK2: U3.1 (Q1); also elsewhere on the board
CLK4: U3.2 (Q2); also elsewhere on the board
CLK8: U3.3 (Q3), U6.11 (Cp); also elsewhere on the board
FX TICK: U6.18 (Q1); also elsewhere on the board
GND: C2.2, C3.2, Cd2.2, Cd3.2, Cd4.2, Cd5.2, Cd6.2, Cd7.2, J9.3, R4.2, U2.7 (GND), U3.8 (GND), U3.12 (~CE), U3.14 (~OE), U4.8 (VSS), U5.1 (A18), U5.16 (VSS), U5.22 (~CE), U5.24 (~OE), U5.30 (A17), U6.1 (OE), U6.10 (GND); also elsewhere on the board
unnamed: C1.2, R5.2, R6.1
unnamed: C2.1, R7.1, U26.12, U26.13, Y1.2
unnamed: C3.1, R7.2, U2.1, U26.11, Y1.1
unnamed: D2.1 (K), U2.12
unnamed: R4.1, R5.1, SW1.1
unnamed: R6.2, U2.13
unnamed: U3.6 (Q6), U5.10 (A2)
unnamed: U3.7 (Q7), U4.10 (CLK), U5.9 (A3)
unnamed: U4.9 (Q0), U5.8 (A4)
unnamed: U4.7 (Q1), U5.7 (A5)
unnamed: U4.6 (Q2), U5.6 (A6)
unnamed: U4.5 (Q3), U5.5 (A7)
unnamed: U4.3 (Q4), U5.27 (A8)
unnamed: U4.2 (Q5), U5.26 (A9)
unnamed: U4.4 (Q6), U5.23 (A10)
unnamed: U4.13 (Q7), U5.25 (A11)
unnamed: U4.12 (Q8), U5.4 (A12)
unnamed: U4.14 (Q9), U5.28 (A13)
unnamed: U4.15 (Q10), U5.29 (A14)
unnamed: U4.1 (Q11), U5.3 (A15)
unnamed: U5.13 (D0), U6.2 (D0)
unnamed: U5.14 (D1), U6.3 (D1)
unnamed: U5.15 (D2), U6.4 (D2)
unnamed: U5.17 (D3), U6.5 (D3)
unnamed: U5.18 (D4), U6.6 (D4)
unnamed: U5.19 (D5), U6.7 (D5)
unnamed: U5.20 (D6), U6.8 (D6)
unnamed: U5.21 (D7), U6.9 (D7)
R/~W: U2.9; also elsewhere on the board
VPixel: U6.17 (Q2); also elsewhere on the board
VReset: U4.11 (Reset), U6.19 (Q0)
~B7: U2.6; also elsewhere on the board
~CLK1: U2.10; also elsewhere on the board
~HSync: U6.16 (Q3); also elsewhere on the board
~PAL/NTSC: J9.2, U5.2 (A16)
~RESET: D2.2 (A), R43.1; also elsewhere on the board
~R/W: U2.8; also elsewhere on the board
~Sync: U6.14 (Q5); also elsewhere on the board
~VIrq: U6.12 (Q7); also elsewhere on the board
~VReset: U6.15 (Q4); also elsewhere on the board
~VSync: U6.13 (Q6); also elsewhere on the board

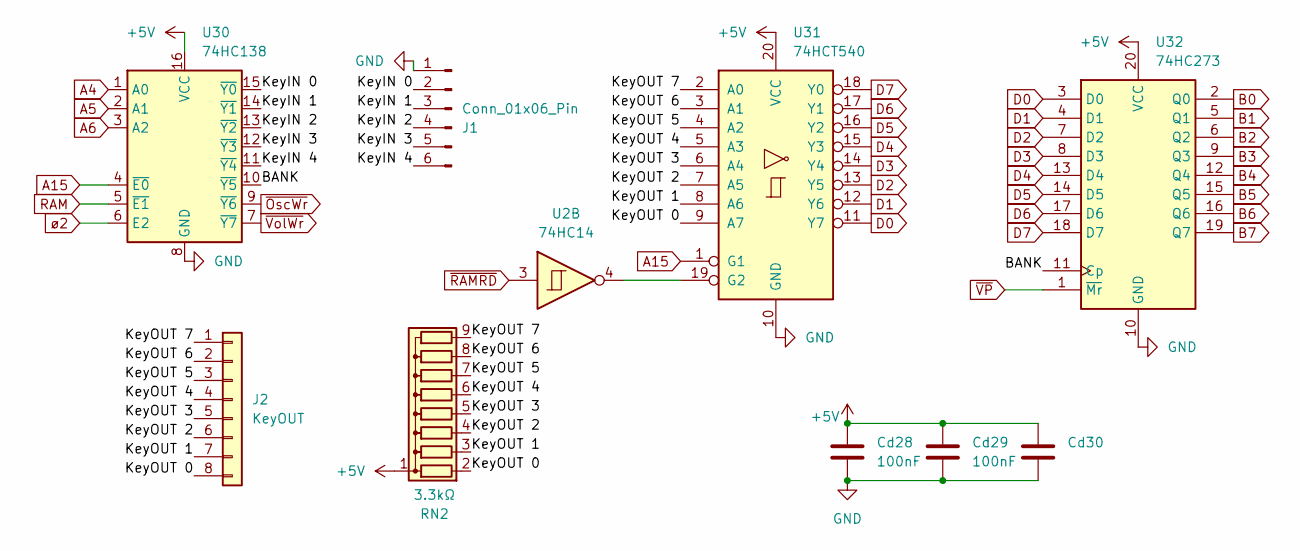
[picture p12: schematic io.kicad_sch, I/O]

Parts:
Cd28, Cd29, Cd30: 100nF; C_Disc_D3.0mm_W1.6mm_P2.50mm
J1: Conn_01x06_Pin; PinHeader_1x06_P2.54mm_Vertical
J2: KeyOUT; PinHeader_1x08_P2.54mm_Vertical
RN2: 3.3kΩ; R_Array_SIP9
U2: 74HC14; DIP-14_W7.62mm_Socket_LongPads_TWEAK
U30: 74HC138; DIP-16_W7.62mm_Socket_LongPads_TWEAK
U31: 74HCT540; DIP-20_W7.62mm_Socket_LongPads_TWEAK
U32: 74HC273; DIP-20_W7.62mm_Socket_LongPads_TWEAK

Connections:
+5V: Cd28.1, Cd29.1, Cd30.1, RN2.1 (common), U30.16 (VCC), U31.20 (VCC), U32.20 (VCC); also elsewhere on the board
/IO/BANK: U30.10 (~Y5), U32.11 (Cp)
/IO/KeyIN 0: J1.2, U30.15 (~Y0)
/IO/KeyIN 1: J1.3, U30.14 (~Y1)
/IO/KeyIN 2: J1.4, U30.13 (~Y2)
/IO/KeyIN 3: J1.5, U30.12 (~Y3)
/IO/KeyIN 4: J1.6, U30.11 (~Y4)
/IO/KeyOUT 0: J2.8, RN2.2 (R1), U31.9 (A7)
/IO/KeyOUT 1: J2.7, RN2.3 (R2), U31.8 (A6)
/IO/KeyOUT 2: J2.6, RN2.4 (R3), U31.7 (A5)
/IO/KeyOUT 3: J2.5, RN2.5 (R4), U31.6 (A4)
/IO/KeyOUT 4: J2.4, RN2.6 (R5), U31.5 (A3)
/IO/KeyOUT 5: J2.3, RN2.7 (R6), U31.4 (A2)
/IO/KeyOUT 6: J2.2, RN2.8 (R7), U31.3 (A1)
/IO/KeyOUT 7: J2.1, RN2.9 (R8), U31.2 (A0)
A4: U30.1 (A0); also elsewhere on the board
A5: U30.2 (A1); also elsewhere on the board
A6: U30.3 (A2); also elsewhere on the board
A15: U30.4 (~E0), U31.1 (G1); also elsewhere on the board
B0: U32.2 (Q0); also elsewhere on the board
B1: U32.5 (Q1); also elsewhere on the board
B2: U32.6 (Q2); also elsewhere on the board
B3: U32.9 (Q3); also elsewhere on the board
B4: U32.12 (Q4); also elsewhere on the board
B5: U32.15 (Q5); also elsewhere on the board
B6: U32.16 (Q6); also elsewhere on the board
B7: U32.19 (Q7); also elsewhere on the board
CLK2: U30.6 (E2); also elsewhere on the board
D0: U31.11 (Y7), U32.3 (D0); also elsewhere on the board
D1: U31.12 (Y6), U32.4 (D1); also elsewhere on the board
D2: U31.13 (Y5), U32.7 (D2); also elsewhere on the board
D3: U31.14 (Y4), U32.8 (D3); also elsewhere on the board
D4: U31.15 (Y3), U32.13 (D4); also elsewhere on the board
D5: U31.16 (Y2), U32.14 (D5); also elsewhere on the board
D6: U31.17 (Y1), U32.17 (D6); also elsewhere on the board
D7: U31.18 (Y0), U32.18 (D7); also elsewhere on the board
GND: Cd28.2, Cd29.2, Cd30.2, J1.1, U30.8 (GND), U31.10 (GND), U32.10 (GND); also elsewhere on the board
unnamed: U2.4, U31.19 (G2)
RAM: U30.5 (~E1); also elsewhere on the board
~OscWr: U30.9 (~Y6); also elsewhere on the board
~RAMRD: U2.3; also elsewhere on the board
~VP: U32.1 (~Mr); also elsewhere on the board
~VolWr: U30.7 (~Y7); also elsewhere on the board

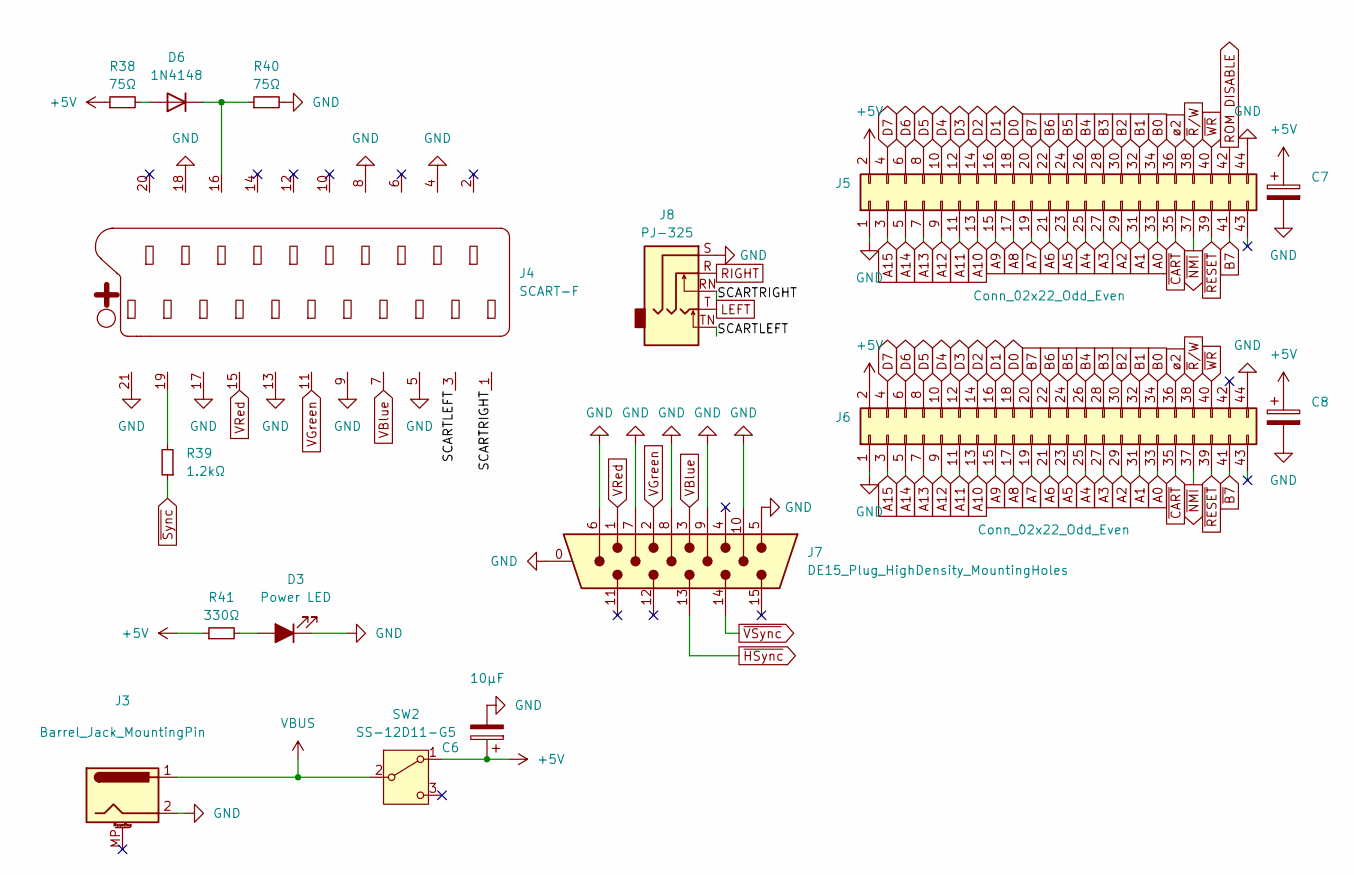
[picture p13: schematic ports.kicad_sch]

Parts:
C6, C7, C8: 10µF; CP_Radial_D6.3mm_P3.8mm
D3: Power LED; LED_Rectangular_W5.0mm_H2.0mm
D6: 1N4148; D_DO-34_SOD68_P7.62mm_Horizontal
J3: Barrel_Jack_MountingPin; BarrelJack_Horizontal
J4: SCART-F; SCART
J5, J6: Conn_02x22_Odd_Even; EdgeHeader_2x22_P2.54mm_Vertical
J7: DE15_Plug_HighDensity_MountingHoles; DSUB-15-HD_Female_Horizontal_P2.29x1.98mm_EdgePinOffset8.35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
J8: PJ-325; Jack_3.5mm_PJ-325
R38, R40: 75Ω; R_Horizontal
R39: 1.2kΩ; R_Horizontal
R41: 330Ω; R_Horizontal
SW2: SS-12D11-G5; SW_Slide_1P2T_CK_OS102011MS2Q

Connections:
+5V: C6.1, C7.1, C8.1, J5.2, J6.2, R38.1, R41.1, SW2.1 (A); also elsewhere on the board
/Ports/SCARTLEFT: J4.3, J8.TN
/Ports/SCARTRIGHT: J4.1, J8.RN
A0: J5.33, J6.33; also elsewhere on the board
A1: J5.31, J6.31; also elsewhere on the board
A2: J5.29, J6.29; also elsewhere on the board
A3: J5.27, J6.27; also elsewhere on the board
A4: J5.25, J6.25; also elsewhere on the board
A5: J5.23, J6.23; also elsewhere on the board
A6: J5.21, J6.21; also elsewhere on the board
A7: J5.19, J6.19; also elsewhere on the board
A8: J5.17, J6.17; also elsewhere on the board
A9: J5.15, J6.15; also elsewhere on the board
A10: J5.13, J6.13; also elsewhere on the board
A11: J5.11, J6.11; also elsewhere on the board
A12: J5.9, J6.9; also elsewhere on the board
A13: J5.7, J6.7; also elsewhere on the board
A14: J5.5, J6.5; also elsewhere on the board
A15: J5.3, J6.3; also elsewhere on the board
B0: J5.34, J6.34; also elsewhere on the board
B1: J5.32, J6.32; also elsewhere on the board
B2: J5.30, J6.30; also elsewhere on the board
B3: J5.28, J6.28; also elsewhere on the board
B4: J5.26, J6.26; also elsewhere on the board
B5: J5.24, J6.24; also elsewhere on the board
B6: J5.22, J6.22; also elsewhere on the board
B7: J5.20, J5.41, J6.20; also elsewhere on the board
CLK2: J5.36, J6.36; also elsewhere on the board
D0: J5.18, J6.18; also elsewhere on the board
D1: J5.16, J6.16; also elsewhere on the board
D2: J5.14, J6.14; also elsewhere on the board
D3: J5.12, J6.12; also elsewhere on the board
D4: J5.10, J6.10; also elsewhere on the board
D5: J5.8, J6.8; also elsewhere on the board
D6: J5.6, J6.6; also elsewhere on the board
D7: J5.4, J6.4; also elsewhere on the board
GND: C6.2, C7.2, C8.2, D3.1 (K), J3.2, J4.4, J4.5, J4.8, J4.9, J4.13, J4.17, J4.18, J4.21, J5.1, J5.44, J6.1, J6.44, J7.0, J7.5, J7.6, J7.7, J7.8, J7.9, J7.10, J8.S, R40.2; also elsewhere on the board
LEFT: J8.T; also elsewhere on the board
unnamed: D3.2 (A), R41.2
unnamed: D6.2 (A), R38.2
unnamed: D6.1 (K), J4.16, R40.1
unnamed: J4.19, R39.2
RIGHT: J8.R; also elsewhere on the board
ROM DISABLE: J5.42; also elsewhere on the board
VBUS: J3.1, SW2.2 (B)
VBlue: J4.7, J7.3; also elsewhere on the board
VGreen: J4.11, J7.2; also elsewhere on the board
VRed: J4.15, J7.1; also elsewhere on the board
~B7: J6.41; also elsewhere on the board
~CART: J5.35, J6.35; also elsewhere on the board
~HSync: J7.13; also elsewhere on the board
~NMI: J5.37, J6.37; also elsewhere on the board
~RESET: J5.39, J6.39; also elsewhere on the board
~R/W: J5.38, J6.38; also elsewhere on the board
~Sync: R39.1; also elsewhere on the board
~VSync: J7.14; also elsewhere on the board
~WR: J5.40, J6.40; also elsewhere on the board

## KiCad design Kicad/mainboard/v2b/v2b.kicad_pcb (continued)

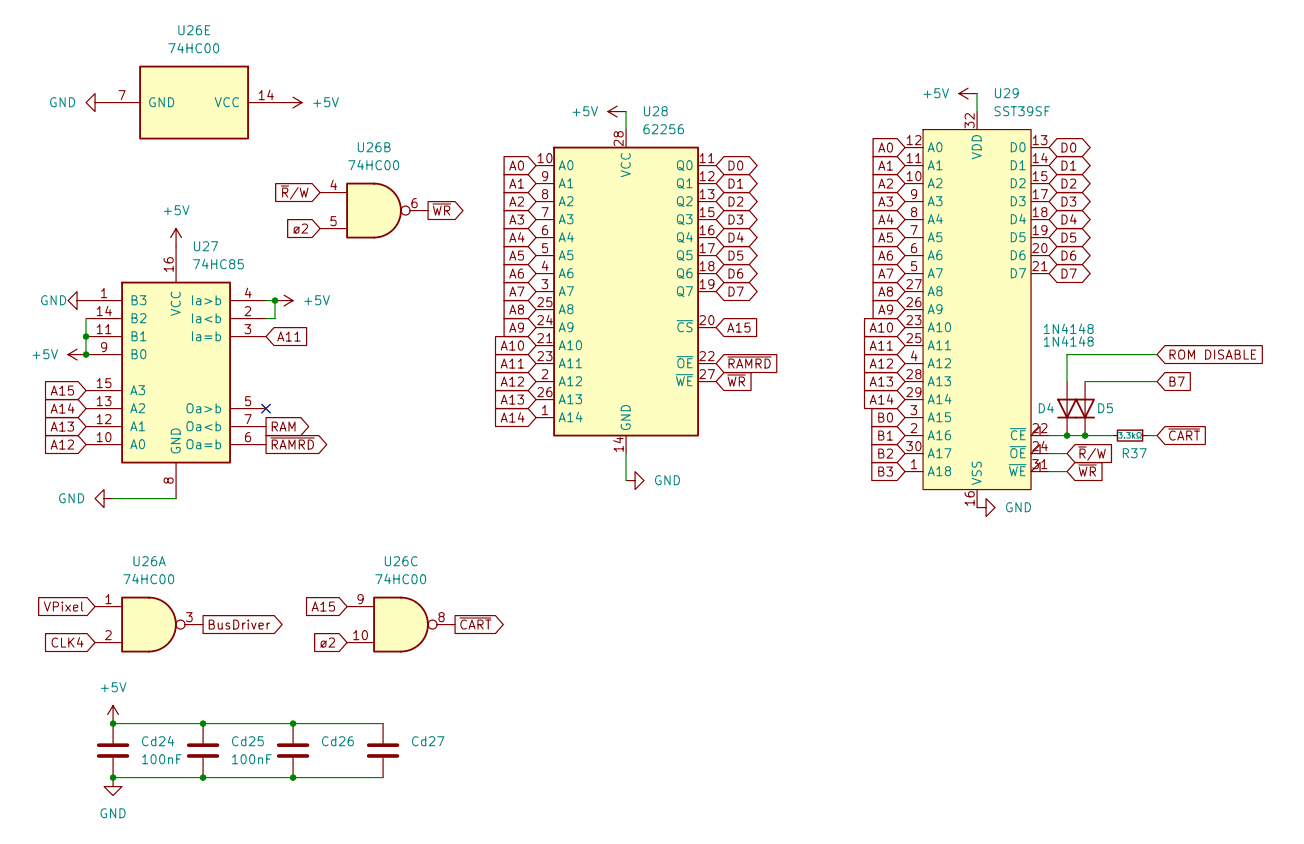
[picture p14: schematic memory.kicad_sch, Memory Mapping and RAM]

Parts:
Cd24, Cd25, Cd26, Cd27: 100nF; C_Disc_D3.0mm_W1.6mm_P2.50mm
D4, D5: 1N4148; D_DO-34_SOD68_P7.62mm_Horizontal
R37: 3.3kΩ; R_Horizontal
U26: 74HC00; DIP-14_W7.62mm_Socket_LongPads_TWEAK
U27: 74HC85; DIP-16_W7.62mm_Socket_LongPads_TWEAK
U28: 62256; DIP-28_W15.24mm_Socket_LongPads_TWEAK
U29: SST39SF; PLCC-32_THT-Socket_TWEAK

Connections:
+5V: Cd24.1, Cd25.1, Cd26.1, Cd27.1, U26.14 (VCC), U27.2 (Ia<b), U27.4 (Ia>b), U27.9 (B0), U27.11 (B1), U27.14 (B2), U27.16 (VCC), U28.28 (VCC), U29.32 (VDD); also elsewhere on the board
A0: U28.10 (A0), U29.12 (A0); also elsewhere on the board
A1: U28.9 (A1), U29.11 (A1); also elsewhere on the board
A2: U28.8 (A2), U29.10 (A2); also elsewhere on the board
A3: U28.7 (A3), U29.9 (A3); also elsewhere on the board
A4: U28.6 (A4), U29.8 (A4); also elsewhere on the board
A5: U28.5 (A5), U29.7 (A5); also elsewhere on the board
A6: U28.4 (A6), U29.6 (A6); also elsewhere on the board
A7: U28.3 (A7), U29.5 (A7); also elsewhere on the board
A8: U28.25 (A8), U29.27 (A8); also elsewhere on the board
A9: U28.24 (A9), U29.26 (A9); also elsewhere on the board
A10: U28.21 (A10), U29.23 (A10); also elsewhere on the board
A11: U27.3 (Ia=b), U28.23 (A11), U29.25 (A11); also elsewhere on the board
A12: U27.10 (A0), U28.2 (A12), U29.4 (A12); also elsewhere on the board
A13: U27.12 (A1), U28.26 (A13), U29.28 (A13); also elsewhere on the board
A14: U27.13 (A2), U28.1 (A14), U29.29 (A14); also elsewhere on the board
A15: U26.9, U27.15 (A3), U28.20 (~CS); also elsewhere on the board
B0: U29.3 (A15); also elsewhere on the board
B1: U29.2 (A16); also elsewhere on the board
B2: U29.30 (A17); also elsewhere on the board
B3: U29.1 (A18); also elsewhere on the board
B7: D5.2 (A); also elsewhere on the board
BusDriver: U26.3; also elsewhere on the board
CLK2: U26.5, U26.10; also elsewhere on the board
CLK4: U26.2; also elsewhere on the board
D0: U28.11 (Q0), U29.13 (D0); also elsewhere on the board
D1: U28.12 (Q1), U29.14 (D1); also elsewhere on the board
D2: U28.13 (Q2), U29.15 (D2); also elsewhere on the board
D3: U28.15 (Q3), U29.17 (D3); also elsewhere on the board
D4: U28.16 (Q4), U29.18 (D4); also elsewhere on the board
D5: U28.17 (Q5), U29.19 (D5); also elsewhere on the board
D6: U28.18 (Q6), U29.20 (D6); also elsewhere on the board
D7: U28.19 (Q7), U29.21 (D7); also elsewhere on the board
GND: Cd24.2, Cd25.2, Cd26.2, Cd27.2, U26.7 (GND), U27.1 (B3), U27.8 (GND), U28.14 (GND), U29.16 (VSS); also elsewhere on the board
unnamed: D4.1 (K), D5.1 (K), R37.2, U29.22 (~CE)
RAM: U27.7 (Oa<b); also elsewhere on the board
ROM DISABLE: D4.2 (A); also elsewhere on the board
VPixel: U26.1; also elsewhere on the board
~CART: R37.1, U26.8; also elsewhere on the board
~RAMRD: U27.6 (Oa=b), U28.22 (~OE); also elsewhere on the board
~R/W: U26.4, U29.24 (~OE); also elsewhere on the board
~WR: U26.6, U28.27 (~WE), U29.31 (~WE); also elsewhere on the board

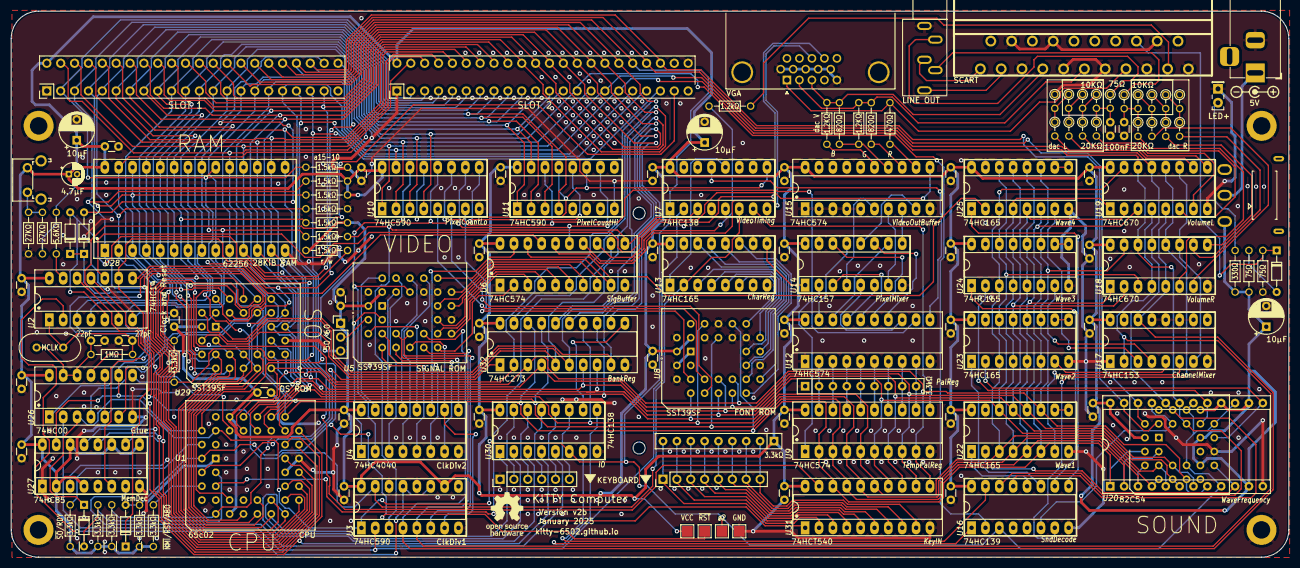
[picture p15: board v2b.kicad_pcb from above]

Board: 2 copper layers, 234.0 x 100.0 mm, 146 parts (0 on the bottom side), 199 nets.

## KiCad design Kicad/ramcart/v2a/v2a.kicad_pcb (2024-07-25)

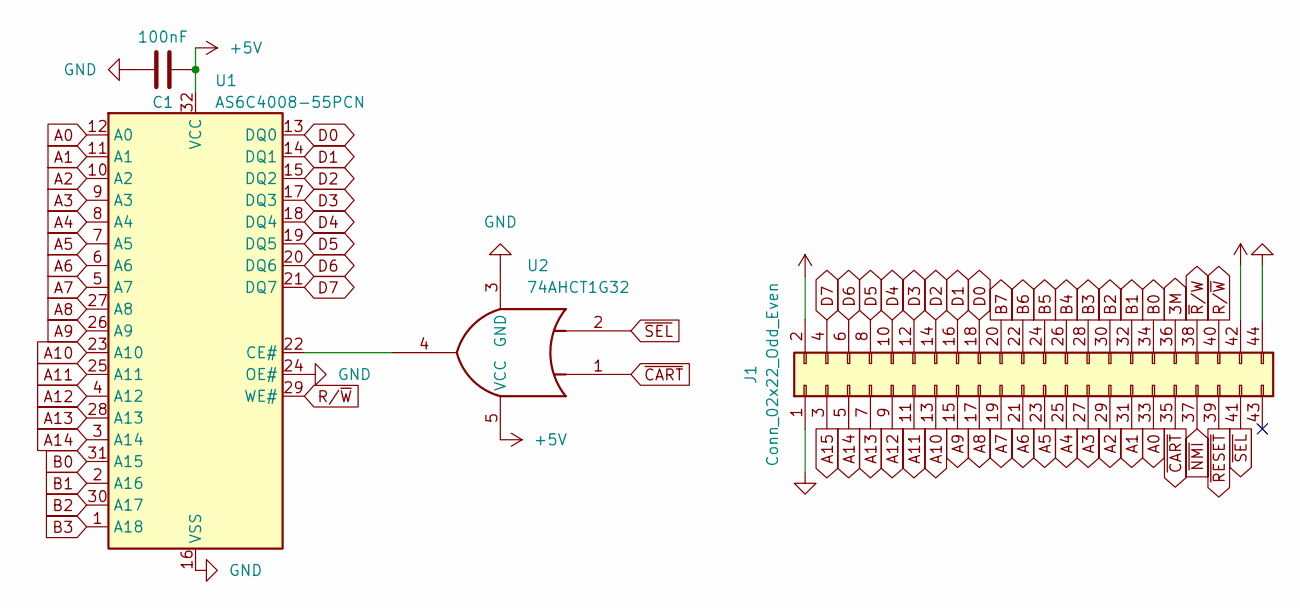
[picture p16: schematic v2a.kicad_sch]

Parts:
C1: 100nF; C_Disc_D3.0mm_W1.6mm_P2.50mm
J1: Conn_02x22_Odd_Even; KITTY_Cart_Edge
U1: AS6C4008-55PCN; DIP-32_W15.24mm_Socket_LongPads
U2: 74AHCT1G32; SOT-23-5

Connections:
3M: J1.36
+5V: C1.2, J1.2, J1.42, U1.32 (VCC), U2.5 (VCC)
A0: J1.33, U1.12 (A0)
A1: J1.31, U1.11 (A1)
A2: J1.29, U1.10 (A2)
A3: J1.27, U1.9 (A3)
A4: J1.25, U1.8 (A4)
A5: J1.23, U1.7 (A5)
A6: J1.21, U1.6 (A6)
A7: J1.19, U1.5 (A7)
A8: J1.17, U1.27 (A8)
A9: J1.15, U1.26 (A9)
A10: J1.13, U1.23 (A10)
A11: J1.11, U1.25 (A11)
A12: J1.9, U1.4 (A12)
A13: J1.7, U1.28 (A13)
A14: J1.5, U1.3 (A14)
A15: J1.3
B0: J1.34, U1.31 (A15)
B1: J1.32, U1.2 (A16)
B2: J1.30, U1.30 (A17)
B3: J1.28, U1.1 (A18)
B4: J1.26
B5: J1.24
B6: J1.22
B7: J1.20
D0: J1.18, U1.13 (DQ0)
D1: J1.16, U1.14 (DQ1)
D2: J1.14, U1.15 (DQ2)
D3: J1.12, U1.17 (DQ3)
D4: J1.10, U1.18 (DQ4)
D5: J1.8, U1.19 (DQ5)
D6: J1.6, U1.20 (DQ6)
D7: J1.4, U1.21 (DQ7)
GND: C1.1, J1.1, J1.44, U1.16 (VSS), U1.24 (OE#), U2.3 (GND)
unnamed: U1.22 (CE#), U2.4
R/~W: J1.40, U1.29 (WE#)
~CART: J1.35, U2.1
~NMI: J1.37
~RESET: J1.39
~R/W: J1.38
~SEL: J1.41, U2.2

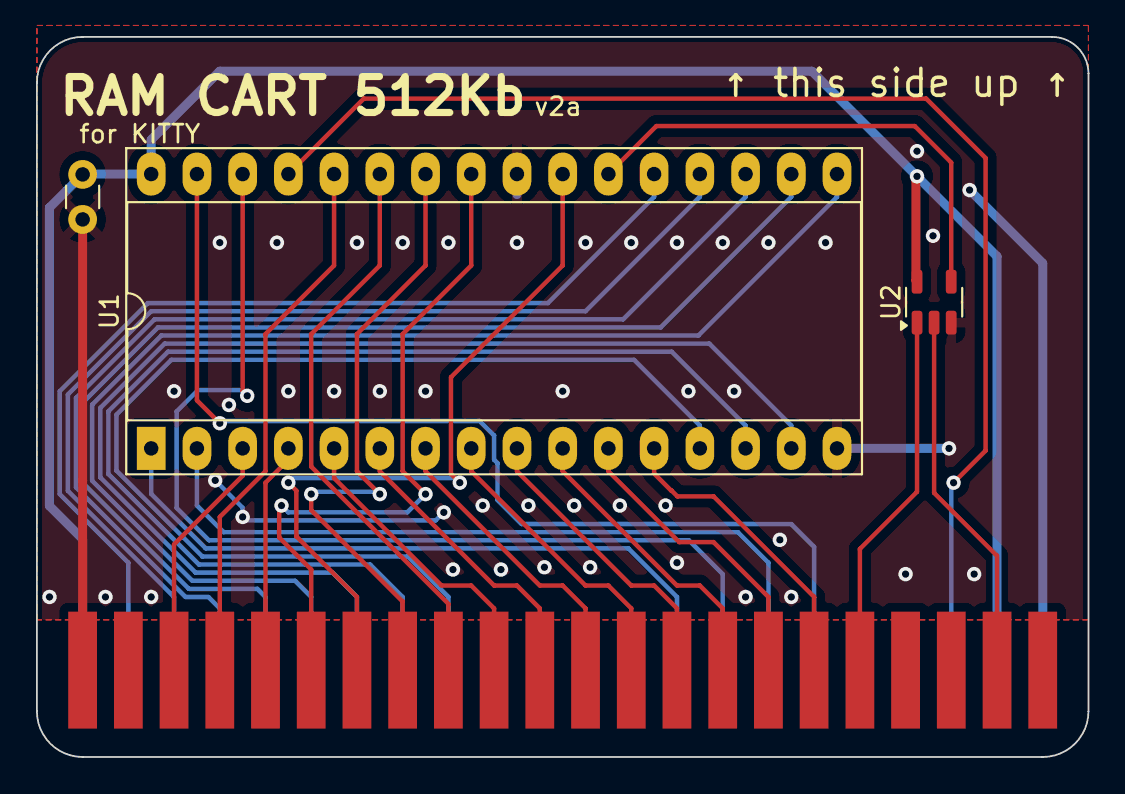
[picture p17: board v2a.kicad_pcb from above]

Board: 2 copper layers, 58.4 x 40.0 mm, 4 parts (0 on the bottom side), 33 nets.

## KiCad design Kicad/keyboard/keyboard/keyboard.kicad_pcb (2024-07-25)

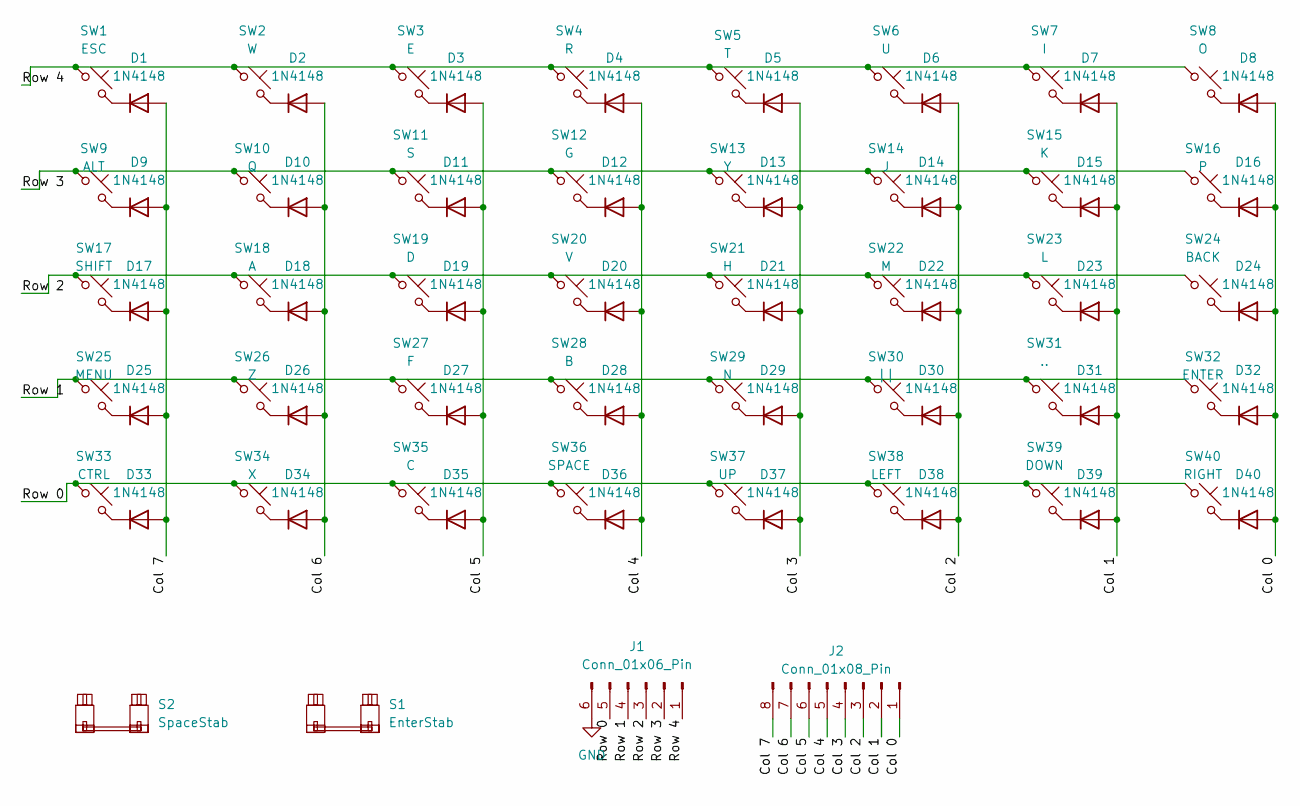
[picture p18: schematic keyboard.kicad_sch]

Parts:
D1, D2, D3, D4, D5, D6, D7, D8, D9, D10, D11, D12, D13, D14, D15, D16, D17, D18, D19, D20, D21, D22, D23, D24, D25, D26, D27, D28, D29, D30, D31, D32, D33, D34, D35, D36, D37, D38, D39, D40: 1N4148; D_DO-35_SOD27_P7.62mm_Horizontal
J1: Conn_01x06_Pin; PinHeader_1x06_P2.54mm_Vertical
J2: Conn_01x08_Pin; PinHeader_1x08_P2.54mm_Vertical
S1: EnterStab; ks27_2u_pcb_cherry_plate_stab
S2: SpaceStab; ks26_6.25u_pcb_cherry_plate
SW1: ESC; SW_Redragon_LowProfile_PCB_1.00u
SW2: W; SW_Redragon_LowProfile_PCB_1.00u
SW3: E; SW_Redragon_LowProfile_PCB_1.00u
SW4: R; SW_Redragon_LowProfile_PCB_1.00u
SW5: T; SW_Redragon_LowProfile_PCB_1.00u
SW6: U; SW_Redragon_LowProfile_PCB_1.00u
SW7: I; SW_Redragon_LowProfile_PCB_1.00u
SW8: O; SW_Redragon_LowProfile_PCB_1.00u
SW9: ALT; SW_Redragon_LowProfile_PCB_1.25u
SW10: Q; SW_Redragon_LowProfile_PCB_1.00u
SW11: S; SW_Redragon_LowProfile_PCB_1.00u
SW12: G; SW_Redragon_LowProfile_PCB_1.00u
SW13: Y; SW_Redragon_LowProfile_PCB_1.00u
SW14: J; SW_Redragon_LowProfile_PCB_1.00u
SW15: K; SW_Redragon_LowProfile_PCB_1.00u
SW16: P; SW_Redragon_LowProfile_PCB_1.00u
SW17: SHIFT; SW_Redragon_LowProfile_PCB_1.75u
SW18: A; SW_Redragon_LowProfile_PCB_1.00u
SW19: D; SW_Redragon_LowProfile_PCB_1.00u
SW20: V; SW_Redragon_LowProfile_PCB_1.00u
SW21: H; SW_Redragon_LowProfile_PCB_1.00u
SW22: M; SW_Redragon_LowProfile_PCB_1.00u
SW23: L; SW_Redragon_LowProfile_PCB_1.00u
SW24: BACK; SW_Redragon_LowProfile_PCB_1.25u
SW25: MENU; SW_Redragon_LowProfile_PCB_1.50u
SW26: Z; SW_Redragon_LowProfile_PCB_1.00u
SW27: F; SW_Redragon_LowProfile_PCB_1.00u
SW28: B; SW_Redragon_LowProfile_PCB_1.00u
SW29: N; SW_Redragon_LowProfile_PCB_1.00u
SW30: ||; SW_Redragon_LowProfile_PCB_1.50u
SW31: ..; SW_Redragon_LowProfile_PCB_1.00u
SW32: ENTER; SW_Redragon_LowProfile_PCB_2.00u
SW33: CTRL; SW_Redragon_LowProfile_PCB_1.50u
SW34: X; SW_Redragon_LowProfile_PCB_1.00u
SW35: C; SW_Redragon_LowProfile_PCB_1.00u
SW36: SPACE; SW_Redragon_LowProfile_PCB_6.25u
SW37: UP; SW_Redragon_LowProfile_PCB_1.00u
SW38: LEFT; SW_Redragon_LowProfile_PCB_1.00u
SW39: DOWN; SW_Redragon_LowProfile_PCB_1.00u
SW40: RIGHT; SW_Redragon_LowProfile_PCB_1.00u

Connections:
/Col 0: D8.2 (A), D16.2 (A), D24.2 (A), D32.2 (A), D40.2 (A), J2.1
/Col 1: D7.2 (A), D15.2 (A), D23.2 (A), D31.2 (A), D39.2 (A), J2.2
/Col 2: D6.2 (A), D14.2 (A), D22.2 (A), D30.2 (A), D38.2 (A), J2.3
/Col 3: D5.2 (A), D13.2 (A), D21.2 (A), D29.2 (A), D37.2 (A), J2.4
/Col 4: D4.2 (A), D12.2 (A), D20.2 (A), D28.2 (A), D36.2 (A), J2.5
/Col 5: D3.2 (A), D11.2 (A), D19.2 (A), D27.2 (A), D35.2 (A), J2.6
/Col 6: D2.2 (A), D10.2 (A), D18.2 (A), D26.2 (A), D34.2 (A), J2.7
/Col 7: D1.2 (A), D9.2 (A), D17.2 (A), D25.2 (A), D33.2 (A), J2.8
/Row 0: J1.5, SW33.1, SW34.1, SW35.1, SW36.1, SW37.1, SW38.1, SW39.1, SW40.1
/Row 1: J1.4, SW25.1, SW26.1, SW27.1, SW28.1, SW29.1, SW30.1, SW31.1, SW32.1
/Row 2: J1.3, SW17.1, SW18.1, SW19.1, SW20.1, SW21.1, SW22.1, SW23.1, SW24.1
/Row 3: J1.2, SW9.1, SW10.1, SW11.1, SW12.1, SW13.1, SW14.1, SW15.1, SW16.1
/Row 4: J1.1, SW1.1, SW2.1, SW3.1, SW4.1, SW5.1, SW6.1, SW7.1, SW8.1
GND: J1.6
unnamed: D1.1 (K), SW1.2
unnamed: D2.1 (K), SW2.2
unnamed: D3.1 (K), SW3.2
unnamed: D4.1 (K), SW4.2
unnamed: D5.1 (K), SW5.2
unnamed: D6.1 (K), SW6.2
unnamed: D7.1 (K), SW7.2
unnamed: D8.1 (K), SW8.2
unnamed: D9.1 (K), SW9.2
unnamed: D10.1 (K), SW10.2
unnamed: D11.1 (K), SW11.2
unnamed: D12.1 (K), SW12.2
unnamed: D13.1 (K), SW13.2
unnamed: D14.1 (K), SW14.2
unnamed: D15.1 (K), SW15.2
unnamed: D16.1 (K), SW16.2
unnamed: D17.1 (K), SW17.2
unnamed: D18.1 (K), SW18.2
unnamed: D19.1 (K), SW19.2
unnamed: D20.1 (K), SW20.2
unnamed: D21.1 (K), SW21.2
unnamed: D22.1 (K), SW22.2
unnamed: D23.1 (K), SW23.2
unnamed: D24.1 (K), SW24.2
unnamed: D25.1 (K), SW25.2
unnamed: D26.1 (K), SW26.2
unnamed: D27.1 (K), SW27.2
unnamed: D28.1 (K), SW28.2
unnamed: D29.1 (K), SW29.2
unnamed: D30.1 (K), SW30.2
unnamed: D31.1 (K), SW31.2
unnamed: D32.1 (K), SW32.2
unnamed: D33.1 (K), SW33.2
unnamed: D34.1 (K), SW34.2
unnamed: D35.1 (K), SW35.2
unnamed: D36.1 (K), SW36.2
unnamed: D37.1 (K), SW37.2
unnamed: D38.1 (K), SW38.2
unnamed: D39.1 (K), SW39.2
unnamed: D40.1 (K), SW40.2

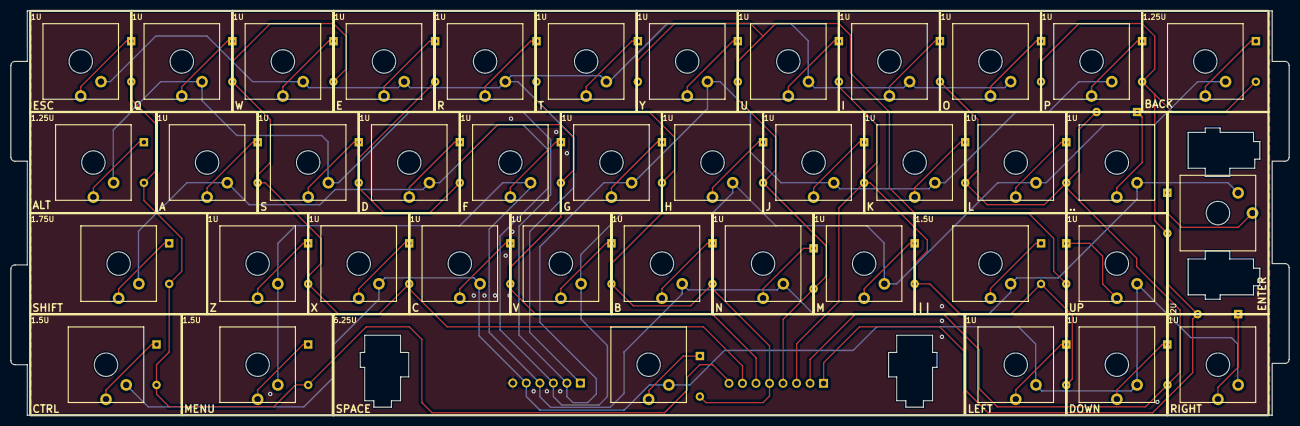
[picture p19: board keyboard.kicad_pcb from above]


Board: 2 copper layers, 240.2 x 76.0 mm, 84 parts (42 on the bottom side), 53 nets.

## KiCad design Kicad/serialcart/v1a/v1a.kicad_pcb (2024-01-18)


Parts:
C1, C2, C3: C_Small; C_Disc_D3.0mm_W1.6mm_P2.50mm
D1, D2, D3: LED_Filled; LED_D3.0mm
J1: Conn_02x22_Odd_Even; KITTY_Cart_Edge
J2: USB_B; USB_B_OST_USB-B1HSxx_Horizontal
R1: 820Ω; R_Axial_DIN0204_L3.6mm_D1.6mm_P7.62mm_Horizontal
U1: 16C550; PLCC-44_THT-Socket
U2: MCP2221A; DIP-14_W7.62mm_Socket

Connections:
3M: J1.36
+5V: C1.2, C3.1, J1.2, R1.2, U1.15 (CS1), U1.24 (~RD), U1.44 (VCC), U2.1 (VDD)
/~OUT1: D3.1 (K), U1.38 (~OUT1)
A0: J1.33, U1.31 (A0)
A1: J1.31, U1.30 (A1)
A2: J1.29, U1.29 (A2)
A3: J1.27
A4: J1.25
A5: J1.23
A6: J1.21
A7: J1.19
A8: J1.17
A9: J1.15
A10: J1.13
A11: J1.11
A12: J1.9
A13: J1.7
A14: J1.5
A15: J1.3
B0: J1.34
B1: J1.32
B2: J1.30
B3: J1.28
B4: J1.26
B5: J1.24
B6: J1.22, J1.42, U1.14 (CS0)
B7: J1.20
D0: J1.18, U1.2 (D0)
D1: J1.16, U1.3 (D1)
D2: J1.14, U1.4 (D2)
D3: J1.12, U1.5 (D3)
D4: J1.10, U1.6 (D4)
D5: J1.8, U1.7 (D5)
D6: J1.6, U1.8 (D6)
D7: J1.4, U1.9 (D7)
GND: C1.1, C2.2, C3.2, J1.1, J1.44, J2.4 (GND), J2.5 (Shield), U1.21 (WR), U1.22 (GND), U1.28 (~ADS), U1.39 (MR), U2.14 (VSS)
unnamed: D1.2 (A), D2.2 (A), D3.2 (A), R1.1
unnamed: D1.1 (K), U2.2 (GP0)
unnamed: D2.1 (K), U2.7 (GP2)
unnamed: J2.3 (D+), U2.13 (D+)
unnamed: J2.2 (D-), U2.12 (D-)
unnamed: U1.10 (RCLK), U1.17 (~BAUDOUT)
unnamed: U1.11 (SIN), U2.6 (UTx)
unnamed: U1.13 (SOUT), U2.5 (URx)
unnamed: U1.18 (XIN), U2.3 (GP1)
unnamed: C2.1, U2.11 (VUSB)
R/~W: J1.40, U1.20 (~WR), U1.25 (RD)
~CART: J1.35, U1.16 (~CS2)
~NMI: J1.37
~RESET: J1.39
~R/W: J1.38
~SEL: J1.41


Board: 2 copper layers, 56.9 x 38.6 mm, 11 parts (0 on the bottom side), 27 nets.

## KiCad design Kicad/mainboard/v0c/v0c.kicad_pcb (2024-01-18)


Board: 2 copper layers, 234.0 x 87.3 mm, 123 parts (0 on the bottom side), 182 nets.

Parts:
C1: 1µF; C_Disc_D3.0mm_W2.0mm_P2.50mm
C2, C3: 33pF; C_Disc_D3.0mm_W2.0mm_P2.50mm
C4, C5, C6, C7, C8, C9, C10, C11, C12, C13, C14, C15, C16, C17, C18, C19, C20, C21, C22, C23, C24, C25, C26, C27, C28, C29, C31, C32: 100nF; C_Disc_D3.0mm_W2.0mm_P2.50mm
C30: C_Polarized; CP_Radial_D6.3mm_P2.50mm
D1: D_Small; D_A-405_P2.54mm_Vertical_KathodeUp
D2: Power; LED_D5.0mm
H1, H2, H3, H4: MountingHole; MountingHole_3.2mm_M3_ISO14580
J1: Barrel_Jack_MountingPin; BarrelJack_Horizontal
J2: SCART-F; SCART
J4, J8: Conn_02x22_Odd_Even; PinSocket_2x22_P2.54mm_Vertical
J5, J9: Conn_01x22; PinHeader_1x22_P2.54mm_Vertical
J6: Conn_01x05_Socket; PinSocket_1x05_P2.54mm_Vertical
J7: Conn_01x09_Socket; PinSocket_1x09_P2.54mm_Vertical
Q1: NPN; TO-92L_HandSolder
R1: 10kΩ; R_Axial_DIN0204_L3.6mm_D1.6mm_P7.62mm_Horizontal
R2: 1MΩ; R_Axial_DIN0204_L3.6mm_D1.6mm_P7.62mm_Horizontal
R3: 390Ω; R_Axial_DIN0204_L3.6mm_D1.6mm_P7.62mm_Horizontal
R4, R5, R7, R8, R10, R11, R14, R15, R18, R19: R2; R_Axial_DIN0204_L3.6mm_D1.6mm_P1.90mm_Vertical
R6, R9, R12, R13, R16, R17: R1; R_Axial_DIN0204_L3.6mm_D1.6mm_P1.90mm_Vertical
R20, R21, R22, R23, R24, R25, R29: 3.3kΩ; R_Axial_DIN0204_L3.6mm_D1.6mm_P7.62mm_Horizontal
R26, R28: 75Ω; R_Axial_DIN0204_L3.6mm_D1.6mm_P7.62mm_Horizontal
R27: 1.2kΩ; R_Axial_DIN0204_L3.6mm_D1.6mm_P7.62mm_Horizontal
R30, R31: 1kΩ; R_Axial_DIN0204_L3.6mm_D1.6mm_P1.90mm_Vertical
R32, R33, R34, R35, R36, R37, R38, R39, R40, R41, R42, R43, R46, R47: R_Small; R_Axial_DIN0204_L3.6mm_D1.6mm_P1.90mm_Vertical
R44: 680Ω; R_Axial_DIN0204_L3.6mm_D1.6mm_P7.62mm_Horizontal
R45: 47kΩ; R_Axial_DIN0204_L3.6mm_D1.6mm_P7.62mm_Horizontal
RN2: 3.3kΩ; R_Array_SIP9
SW1: SW_DPDT_x2; SW_CuK_JS202011AQN_DPDT_Angled
SW2: RESET; SW_PUSH_6mm
U1: 74HC4520; DIP-16_W7.62mm_Socket_LongPads
U2: 74HC14; DIP-14_W7.62mm_Socket_LongPads
U3: 74HC4040; DIP-16_W7.62mm_Socket_LongPads
U4, U23: SST39F; PLCC-32_THT-Socket
U5, U10, U13, U16: 74HC574; DIP-20_W7.62mm_Socket_LongPads
U6: 65c02; PLCC-44_THT-Socket
U7: 74HC00; DIP-14_W7.62mm_Socket_LongPads
U8: 74HC85; DIP-16_W7.62mm_Socket_LongPads
U9, U24: 74HC138; DIP-16_W7.62mm_Socket_LongPads
U11, U12: 74HC590A; DIP-16_W7.62mm_Socket_LongPads
U14: 74HC166; DIP-16_W7.62mm_Socket_LongPads
U15: 74HC157; DIP-16_W7.62mm_Socket_LongPads
U17: 82c54; DIP-24_W15.24mm_Socket_LongPads
U18, U19: 74HC670; DIP-16_W7.62mm_Socket_LongPads
U20: 74HCT153; DIP-16_W7.62mm_Socket_LongPads
U21: 62256; DIP-28_W15.24mm_Socket_LongPads
U25: 74HC541; DIP-20_W7.62mm_Socket_LongPads
U26: 74HC273; DIP-20_W7.62mm_Socket_LongPads
Y1: 12 Mhz; Crystal_HC52-8mm_Vertical

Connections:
1M: U1.5 (Q3), U7.2, U9.2 (A1), U17.9 (CLK0), U17.15 (CLK1), U17.18 (CLK2), U18.5 (Ra), U19.5 (Ra), U20.14 (S0)
3M: J4.36, J8.36, U1.4 (Q2), U6.41 (ϕ0), U7.5, U7.10, U7.12, U9.1 (A0)
6M: U1.3 (Q1), U2.11, U14.7 (Clk)
12M: U1.1 (CK), U2.12
750K: R20.2, U1.6 (Q4), U1.9 (CK), U5.11 (Cp), U9.3 (A2), U18.4 (Rb), U19.4 (Rb), U20.2 (S1)
+5V: C4.1, C5.1, C6.1, C7.1, C8.1, C9.1, C10.1, C11.1, C12.1, C13.1, C14.1, C15.1, C16.1, C17.1, C18.1, C19.1, C20.1, C21.1, C22.1, C23.1, C24.1, C25.1, C26.1, C27.1, C28.1, C29.1, C30.1, J4.2, J7.1, J8.2, R1.2, R21.2, R23.2, R24.2, R26.1, R29.2, R31.1, R44.1, SW1.2 (B), SW1.5 (B), U1.2 (Enable), U1.10 (Enable), U1.16 (VDD), U2.14 (VCC), U3.16 (VDD), U4.31 (~WE), U4.32 (VDD), U5.20 (VCC), U6.9 (VDD), U6.37 (VDD), U6.42 (~SO), U7.14 (VCC), U8.3 (Ia=b), U8.9 (B0), U8.11 (B1), U8.14 (B2), U8.16 (VCC), U9.6 (E2), U9.16 (VCC), U10.20 (VCC), U11.16 (VCC), U12.16 (VCC), U13.20 (VCC), U14.9 (Clr), U14.16 (VCC), U15.16 (VCC), U16.20 (VCC), U17.11 (G0), U17.14 (G1), U17.16 (G2), U17.24 (VCC), U18.16 (VCC), U19.16 (VCC), U20.16 (VCC), U21.28 (VCC), U23.31 (~WE), U23.32 (VDD), U24.6 (E2), U24.16 (VCC), U25.20 (VCC), U26.20 (VCC)
/Audio/L0: R5.2, U19.10 (Q1)
/Audio/L1: R10.2, U19.9 (Q2)
/Audio/L2: R14.2, U19.7 (Q3)
/Audio/L3: R18.2, U19.6 (Q4)
/Audio/Osc 1: U17.10 (OUT0), U20.6 (I0a)
/Audio/Osc 2: U17.13 (OUT1), U20.5 (I1a)
/Audio/Osc 3: U17.17 (OUT2), U20.4 (I2a)
/Audio/R0: R8.2, U18.10 (Q1)
/Audio/R1: R11.2, U18.9 (Q2)
/Audio/R2: R15.2, U18.7 (Q3)
/Audio/R3: R19.2, U18.6 (Q4)
/Audio/Sout: U18.11 (~Er), U19.11 (~Er), U20.7 (Za)
/IO/BANK: U24.10 (~Y5), U26.11 (Cp)
/IO/KeyIN 0: J6.1, U24.15 (~Y0)
/IO/KeyIN 1: J6.2, U24.14 (~Y1)
/IO/KeyIN 2: J6.3, U24.13 (~Y2)
/IO/KeyIN 3: J6.4, U24.12 (~Y3)
/IO/KeyIN 4: J6.5, U24.11 (~Y4)
/IO/KeyOUT 0: J7.2, U25.2 (A0)
/IO/KeyOUT 1: J7.3, U25.3 (A1)
/IO/KeyOUT 2: J7.4, U25.4 (A2)
/IO/KeyOUT 3: J7.5, U25.5 (A3)
/IO/KeyOUT 4: J7.6, U25.6 (A4)
/IO/KeyOUT 5: J7.7, U25.7 (A5)
/IO/KeyOUT 6: J7.8, U25.8 (A6)
/IO/KeyOUT 7: J7.9, U25.9 (A7)
/Ports/~B7: J8.41, J9.21, Q1.1 (C), R31.2
/Video/Pa0: U13.12 (Q7), U15.2 (I0a)
/Video/Pa1: U13.13 (Q6), U15.5 (I0b)
/Video/Pa2: U13.14 (Q5), U15.11 (I0c)
/Video/Pa3: U13.15 (Q4), U15.14 (I0d)
/Video/Pb0: U13.16 (Q3), U15.3 (I1a)
/Video/Pb1: U13.17 (Q2), U15.6 (I1b)
/Video/Pb2: U13.18 (Q1), U15.10 (I1c)
/Video/Pb3: U13.19 (Q0), U15.13 (I1d)
/Video/Y0: U11.5 (Q5), U23.8 (A4)
/Video/Y1: U11.6 (Q6), U23.7 (A5)
/Video/Y2: U11.7 (Q7), U23.6 (A6)
A0: J4.33, J5.17, J8.33, J9.17, U6.10 (A0), U11.15 (Q0), U17.19 (A0), U18.14 (Wa), U19.14 (Wa), U21.10 (A0)
A1: J4.31, J5.16, J8.31, J9.16, U6.11 (A1), U11.1 (Q1), U17.20 (A1), U18.13 (Wb), U19.13 (Wb), U21.9 (A1)
A2: J4.29, J5.15, J8.29, J9.15, U6.13 (A2), U11.2 (Q2), U21.8 (A2)
A3: J4.27, J5.14, J8.27, J9.14, U6.14 (A3), U11.3 (Q3), U21.7 (A3)
A4: J4.25, J5.13, J8.25, J9.13, U6.15 (A4), U11.4 (Q4), U21.6 (A4), U24.1 (A0)
A5: J4.23, J5.12, J8.23, J9.12, U6.16 (A5), U12.15 (Q0), U21.5 (A5), U24.2 (A1)
A6: J4.21, J5.11, J8.21, J9.11, U6.17 (A6), U12.1 (Q1), U21.4 (A6), U24.3 (A2)
A7: J4.19, J5.10, J8.19, J9.10, U6.18 (A7), U12.2 (Q2), U21.3 (A7), U25.1 (G1)
A8: J4.17, J5.9, J8.17, J9.9, U6.19 (A8), U12.3 (Q3), U21.25 (A8)
A9: J4.15, J5.8, J8.15, J9.8, U6.20 (A9), U12.4 (Q4), U20.3 (I3a), U21.24 (A9)
A10: J4.13, J5.7, J8.13, J9.7, R20.1, U6.21 (A10), U21.21 (A10)
A11: J4.11, J5.6, J8.11, J9.6, R21.1, U6.22 (A11), U21.23 (A11)
A12: J4.9, J5.5, J8.9, J9.5, R22.1, U6.25 (A12), U8.10 (A0), U21.2 (A12)
A13: J4.7, J5.4, J8.7, J9.4, R23.1, U6.26 (A13), U8.12 (A1), U21.26 (A13)
A14: J4.5, J5.3, J8.5, J9.3, R24.1, U6.27 (A14), U8.13 (A2), U21.1 (A14)
A15: J4.3, J5.2, J8.3, J9.2, R25.1, U6.28 (A15), U8.15 (A3)
B0: J4.34, J8.34, U26.2 (Q0)
B1: J4.32, J8.32, U26.5 (Q1)
B2: J4.30, J8.30, U26.6 (Q2)
B3: J4.28, J8.28, U26.9 (Q3)
B4: J4.26, J8.26, U26.12 (Q4)
B5: J4.24, J8.24, U26.15 (Q5)
B6: J4.22, J8.22, U26.16 (Q6)
B7: J4.20, J4.41, J5.21, J8.20, R30.1, U26.19 (Q7)
BusDriver: U6.3 (RDY), U6.40 (BE), U7.3, U11.14 (~OE), U12.14 (~OE)
D0: J4.18, J8.18, U6.36 (D0), U10.9 (D7), U17.8 (D0), U18.15 (D1), U21.11 (Q0), U23.12 (A0), U25.18 (Y0), U26.3 (D0)
D1: J4.16, J8.16, U6.35 (D1), U10.8 (D6), U17.7 (D1), U18.1 (D2), U21.12 (Q1), U23.11 (A1), U25.17 (Y1), U26.4 (D1)
D2: J4.14, J8.14, U6.34 (D2), U10.7 (D5), U17.6 (D2), U18.2 (D3), U21.13 (Q2), U23.10 (A2), U25.16 (Y2), U26.7 (D2)
D3: J4.12, J8.12, U6.33 (D3), U10.6 (D4), U17.5 (D3), U18.3 (D4), U21.15 (Q3), U23.9 (A3), U25.15 (Y3), U26.8 (D3)
D4: J4.10, J8.10, U6.32 (D4), U10.5 (D3), U17.4 (D4), U19.15 (D1), U21.16 (Q4), U23.5 (A7), U25.14 (Y4), U26.13 (D4)
D5: J4.8, J8.8, U6.31 (D5), U10.4 (D2), U17.3 (D5), U19.1 (D2), U21.17 (Q5), U23.27 (A8), U25.13 (Y5), U26.14 (D5)
D6: J4.6, J8.6, U6.30 (D6), U10.3 (D1), U17.2 (D6), U19.2 (D3), U21.18 (Q6), U23.26 (A9), U25.12 (Y6), U26.17 (D6)
D7: J4.4, J8.4, U6.29 (D7), U10.2 (D0), U17.1 (D7), U19.3 (D4), U21.19 (Q7), U23.23 (A10), U25.11 (Y7), U26.18 (D7)
GND: C1.1, C2.2, C3.2, C4.2, C5.2, C6.2, C7.2, C8.2, C9.2, C10.2, C11.2, C12.2, C13.2, C14.2, C15.2, C16.2, C17.2, C18.2, C19.2, C20.2, C21.2, C22.2, C23.2, C24.2, C25.2, C26.2, C27.2, C28.2, C29.2, C30.2, C31.1, C32.1, D2.1 (K), J1.2, J2.4, J2.5, J2.8, J2.9, J2.13, J2.17, J2.18, J2.21, J4.1, J4.44, J5.1, J8.1, J8.44, J9.1, Q1.3 (E), R4.1, R7.1, R22.2, R25.2, R28.2, RN2.1 (common), SW2.2, U1.7 (Reset), U1.8 (VSS), U2.7 (GND), U3.8 (VSS), U4.1 (A18), U4.2 (A16), U4.3 (A15), U4.16 (VSS), U4.22 (~CE), U4.24 (~OE), U4.28 (A13), U4.29 (A14), U4.30 (A17), U5.1 (OE), U5.10 (GND), U6.1 (VSS), U6.23 (VSS), U6.24 (VSS), U7.7 (GND), U8.1 (B3), U8.2 (Ia<b), U8.4 (Ia>b), U8.8 (GND), U9.4 (~E0), U9.5 (~E1), U9.8 (GND), U10.10 (GND), U11.8 (GND), U12.8 (GND), U13.1 (OE), U13.10 (GND), U14.1 (Ds), U14.6 (CE), U14.8 (GND), U15.8 (GND), U15.15 (E), U16.1 (OE), U16.6 (D4), U16.7 (D5), U16.8 (D6), U16.9 (D7), U16.10 (GND), U17.12 (GND), U18.8 (GND), U19.8 (GND), U20.1 (Ea), U20.8 (GND), U20.10 (I0b), U20.11 (I1b), U20.12 (I2b), U20.13 (I3b), U20.15 (Eb), U21.14 (GND), U21.22 (~OE), U23.1 (A18), U23.2 (A16), U23.3 (A15), U23.4 (A12), U23.16 (VSS), U23.22 (~CE), U23.24 (~OE), U23.25 (A11), U23.28 (A13), U23.29 (A14), U23.30 (A17), U24.5 (~E1), U24.8 (GND), U25.10 (GND), U26.10 (GND)
LEFT: J4.42, J8.42, R16.2, R18.1, R46.2
unnamed: C1.2, R45.1, U2.1
unnamed: C2.1, R2.1, U2.5, Y1.1
unnamed: C3.1, R3.1, U2.6, U2.13
unnamed: D1.2 (A), R26.2
unnamed: D1.1 (K), J2.16, R28.1
unnamed: D2.2 (A), R44.2
unnamed: C31.2, J2.1, R47.1
unnamed: C32.2, J2.3, R46.1
unnamed: J2.19, R27.2
unnamed: Q1.2 (B), R30.2
unnamed: R1.1, R45.2, SW2.1
unnamed: R2.2, R3.2, Y1.2
unnamed: R4.2, R5.1, R6.1
unnamed: R7.2, R8.1, R9.1
unnamed: R6.2, R10.1, R12.1
unnamed: R9.2, R11.1, R13.1
unnamed: R12.2, R14.1, R16.1
unnamed: R13.2, R15.1, R17.1
unnamed: R32.2, R36.1
unnamed: R33.2, R37.1
unnamed: R34.2, R38.1
unnamed: R35.2, R39.1
unnamed: R36.2, R40.1
unnamed: R37.2, R41.1
unnamed: R38.2, R42.1
unnamed: R39.2, R43.1
unnamed: RN2.2 (R1), U10.19 (Q0), U13.2 (D0)
unnamed: RN2.3 (R2), U10.18 (Q1), U13.3 (D1)
unnamed: RN2.4 (R3), U10.17 (Q2), U13.4 (D2)
unnamed: RN2.5 (R4), U10.16 (Q3), U13.5 (D3)
unnamed: RN2.6 (R5), U10.15 (Q4), U13.6 (D4)
unnamed: RN2.7 (R6), U10.14 (Q5), U13.7 (D5)
unnamed: RN2.8 (R7), U10.13 (Q6), U13.8 (D6)
unnamed: RN2.9 (R8), U10.12 (Q7), U13.9 (D7)
unnamed: U1.12 (Q2), U4.12 (A0)
unnamed: U1.13 (Q3), U4.11 (A1)
unnamed: U1.14 (Q4), U3.10 (CLK), U4.10 (A2)
unnamed: U3.9 (Q0), U4.9 (A3)
unnamed: U3.7 (Q1), U4.8 (A4)
unnamed: U3.6 (Q2), U4.7 (A5)
unnamed: U3.5 (Q3), U4.6 (A6)
unnamed: U3.3 (Q4), U4.5 (A7)
unnamed: U3.2 (Q5), U4.27 (A8)
unnamed: U3.4 (Q6), U4.26 (A9)
unnamed: U3.13 (Q7), U4.23 (A10)
unnamed: U3.12 (Q8), U4.25 (A11)
unnamed: U3.14 (Q9), U4.4 (A12)
unnamed: U4.13 (D0), U5.2 (D0)
unnamed: U4.14 (D1), U5.3 (D1)
unnamed: U4.15 (D2), U5.4 (D2)
unnamed: U4.17 (D3), U5.5 (D3)
unnamed: U4.18 (D4), U5.6 (D4)
unnamed: U4.19 (D5), U5.7 (D5)
unnamed: U4.20 (D6), U5.8 (D6)
unnamed: U4.21 (D7), U5.9 (D7)
unnamed: U7.4, U8.7 (Oa<b)
unnamed: U7.9, U8.6 (Oa=b)
unnamed: U7.13, U8.5 (Oa>b)
unnamed: U11.9 (~RCO), U12.12 (~CE)
unnamed: U14.2 (A), U23.13 (D0)
unnamed: U14.3 (B), U23.14 (D1)
unnamed: U14.4 (C), U23.15 (D2)
unnamed: U14.5 (D), U23.17 (D3)
unnamed: U14.10 (E), U23.18 (D4)
unnamed: U14.11 (F), U23.19 (D5)
unnamed: U14.12 (G), U23.20 (D6)
unnamed: U14.14 (H), U23.21 (D7)
unnamed: U14.13 (Qh), U15.1 (S)
unnamed: U15.4 (Za), U16.2 (D0)
unnamed: U15.7 (Zb), U16.3 (D1)
unnamed: U15.9 (Zc), U16.4 (D2)
unnamed: U15.12 (Zd), U16.5 (D3)
unnamed: R32.1, U16.19 (Q0)
unnamed: R33.1, U16.18 (Q1)
unnamed: R34.1, U16.17 (Q2)
unnamed: R35.1, U16.16 (Q3)
RESET: U2.2, U2.3
RIGHT: J4.43, J5.22, J8.43, J9.22, R17.2, R19.1, R47.2
R/~W: J4.40, J8.40, U2.9, U6.38 (R/~W), U17.23 (~WR), U21.27 (~WE)
VBUS: J1.1, SW1.3 (C), SW1.6 (C)
VBlue: J2.7, R41.2
VGreen: J2.11, R42.2
VPixel: U5.17 (Q2), U7.1
VRed: J2.15, R43.2
VReset: U1.15 (Reset), U3.11 (Reset), U5.19 (Q0)
~6M: U2.10, U16.11 (Cp)
~CART: J4.35, J5.18, J8.35, J9.18, U7.11
~CharTickReg: U9.14 (~Y1), U11.13 (CPR), U12.13 (CPR)
~CharTick: U9.15 (~Y0), U11.11 (CPC), U12.11 (CPC)
~ChrGet: U9.7 (~Y7), U14.15 (PE)
~IO: U7.8, U24.4 (~E0), U25.19 (G2)
~NMI: J4.37, J5.19, J8.37, J9.19, R29.1, U6.7 (~NMI)
~OscWr: U17.21 (~CS), U24.9 (~Y6)
~PalGet: U9.12 (~Y3), U10.11 (Cp)
~PalPush: U9.9 (~Y6), U13.11 (Cp)
~RAM: U7.6, U21.20 (~CS)
~RESET: J4.39, J5.20, J8.39, J9.20, U2.4, U6.44 (~RES), U26.1 (~Mr)
~R/W: J4.38, J8.38, U2.8, U17.22 (~RD)
~VIrq: U5.12 (Q7), U6.5 (~IRQ)
~VPixel: U5.13 (Q6), U10.1 (OE), U11.12 (~CE)
~VReset: U5.15 (Q4), U11.10 (~MRC), U12.10 (~MRC)
~VSync: R27.1, U5.14 (Q5)
~VolWr: U18.12 (~Ew), U19.12 (~Ew), U24.7 (~Y7)

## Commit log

2024-01-18 update kicad files
    [ClockReset.kicad_sch, audio.kicad_sch, io.kicad_sch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]
2024-04-26 big v1b commit
    [ClockReset.kicad_sch, audio.kicad_sch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]
2024-06-02 v2a update
    [ClockReset.kicad_sch, audio.kicad_sch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]
2024-06-02 add schematic
2024-07-25 Update board files
    [ClockReset.kicad_sch, audio.kicad_sch, io.kicad_sch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]
2025-01-18 Updated pcb files and python scripts
    [ClockReset.kicad_sch, audio.kicad_sch, io.kicad_sch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]
